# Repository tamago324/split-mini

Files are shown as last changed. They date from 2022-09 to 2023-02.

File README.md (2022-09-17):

# split mini

小さな分割キーボードです。

## ライセンス

<br />この 作品 は <a rel="license" href="http://creativecommons.org/licenses/by/4.0/">クリエイティブ・コモンズ 表示 4.0 国際 ライセンス</a>の下に提供されています。

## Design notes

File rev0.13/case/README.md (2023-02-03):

## ボトムケースとトップケースをねじ止めする

* [ネジ](https://wilco.jp/products/F/FPP-N.html#page1)
  * M2 の 5mm

## ケースのデータ (Onshape)

https://cad.onshape.com/documents/96d7513a54998d2b6436f8c3/w/2520ae499280115528b36742/e/f078bf5b49cbb926b5d52385

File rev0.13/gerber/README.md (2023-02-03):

## Elecrow に発注するとき

* split-mini__left_94.8x81.85mm_for_Elecrow.zip
  * 1.2mm
* split-mini__right_94.8x81.85mm_for_Elecrow.zip
  * 1.2mm
* split-mini__switch_plate_94.8x83.85mm_for_Elecrow.zip
  * 1.6mm

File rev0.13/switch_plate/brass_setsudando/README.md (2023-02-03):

とりあえず FR4 で組み立ててみることにしたため、まだ発注していない

## 切断堂さんに発注するときに使用する DXF ファイル

切断堂さんに発注するときには、スイッチの穴は 13.85 にする必要があるため、そのようにしている

1つのDXFファイルでオモテウラで2つを発注すれば良いのかもって思っているけど、それでできるのかはメールで問い合わせて見る必要がありそう

### 発注

* 厚さ：1.5mm
* 表面仕上げ：サンドブラスト

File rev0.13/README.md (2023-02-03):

## split mini rev0.13

* [KLE](http://www.keyboard-layout-editor.com/#/gists/a34cca681a2130594f6d9f4207fc3f27)
* https://kbplate.ai03.com/ でプレートデータを作成
  * width: 17
  * height: 17
* 左右分割キーボード
* 狭ピッチ
  * キーキャップは専用のものを使う (底面が16mmのやつを使うことにする)
  * [雰囲気で作ったキーキャップ](https://github.com/tamago324/small-keycaps)
* MXのみ 対応
* 100mmx100mm以下のため、Elecrow で1ドルで発注可能
* [QMK firmware](https://github.com/tamago324/qmk_firmware/tree/tamago324/keyboards/tamago324/splitmini)
  * rev13 のディレクトリのため、`nix-shell --run 'sudo make tamago324/splitmini/rev13:tamago324:flash'` のようにして書き込み可能

## 部品一覧

片手分

| 名前 | 値 | 備考 | 個数 | 部品番号 | リンク |
| --- | --- | --- | ---  | --- | --- |
| コンデンサ | 0.1uF | 0805 (2012) | 3 | C2、C3、C4 | [Digikey][1]  |
| コンデンサ | 10uF  | 0805 (2012) | 1 | C5 | [Digikey][2]  |
| コンデンサ | 1uF | 0805 (2012) | 1 | C1 | [Digikey][3]  |
| コンデンサ | 22pF  | 0805 (2012) | 2 | C6、C7 | [Digikey][4]  |
| ヒューズ | 500mA | 1206 (3216) | 1 | F1 | [Digikey][5]  |
| 抵抗 | 5.1kΩ  | 0805 (2012) | 2 | R1、R2 | [モノタロウ][13]  |
| 抵抗 | 22 | 0805 (2012) | 2 | R3、R4 | [Digikey][7]  |
| 抵抗 | 10kΩ  | 0805 (2012) | 2 | R5、R6 | [Digikey][6]  |
| 水晶発振子 | 16MHz | 3225 4pin 3.2x2.5mm | 1 | Y1 | [Digikey][8]  |
| TRRSジャック (MJ-4PP-9) | - | - | 1 | J2 | [遊舎工房][9] |
| ATmega32U4 | - | 10x10mm P0.8mm | 1 | U1 | [Digikey][10] |
| USBコネクタ (Type-C) | - | 5077CR-16SMC2-BK-TR | 1 | J1 | [秋月電子][11] |
| リセットスイッチ | - | SKRPACE010 | 1 | RESET1 | [秋月電子][12] |

### 実際に購入したところ

| 名前 | 値 | 備考 | 個数 | 部品番号 | リンク |
| --- | --- | --- | ---  | --- | --- |
| コンデンサ | 0.1uF | 0805 (2012) | 3 | C2、C3、C4 | [秋月電子][21]  |
| コンデンサ | 10uF  | 0805 (2012) | 1 | C5 | [秋月電子][22]  |
| コンデンサ | 1uF | 0805 (2012) | 1 | C1 | [秋月電子][23]  |
| コンデンサ | 22pF  | 0805 (2012) | 2 | C6、C7 | [mouser][24]  |
| ヒューズ | 500mA | 1206 (3216) | 1 | F1 | [mouser][25]  |
| 抵抗 | 5.1kΩ  | 0805 (2012) | 2 | R1、R2 | [モノタロウ][13]  |
| 抵抗 | 22 | 0805 (2012) | 2 | R3、R4 | [mouser][27]  |
| 抵抗 | 10kΩ  | 0805 (2012) | 2 | R5、R6 | [秋月電子][26]  |
| 水晶発振子 | 16MHz | 3225 4pin 3.2x2.5mm | 1 | Y1 | [秋月電子][28]  |
| TRRSジャック (MJ-4PP-9) | - | - | 1 | J1 | [遊舎工房][29] |
| ATmega32U4 | - | 10x10mm P0.8mm | 1 | U1 | [秋月電子][30] |
| USBコネクタ (Type-C) | - | 5077CR-16SMC2-BK-TR | 1 | J1 | [秋月電子][11] |
| リセットスイッチ | - | SKRPACE010 | 1 | SW1 | [秋月電子][12] |

### 画像

#### PCB

#### ケース

## 参考情報

* https://github.com/ruiqimao/keyboard-pcb-guide
* [ATmega32u2直付けのキーパッドを作ろう！](https://taro-hayashi.github.io/LetsMakeaKeypadWithAtmega32u2/)
* [ATMega32u4を使う場合の設計メモ\.md](https://gist.github.com/s-show/286ffb1f5d9c886b514ff7a37e6d8d37)
* [ATmega32U4について学んだこと](https://zenn.dev/koron/articles/a2e220d73800ba)
* [Using USB Type\-C on hobyist projects – The blog of Tyler Ward \(aka scorpia\)](https://www.scorpia.co.uk/2016/03/17/using-usb-type-c-on-hobyist-projects/)

[1]:https://www.digikey.com/product-detail/en/samsung-electro-mechanics/CL21B104MBCNNNC/1276-2450-1-ND/3890536
[2]:https://www.digikey.com/product-detail/en/samsung-electro-mechanics/CL21A106KOQNNNG/1276-6455-1-ND/5958083
[3]:https://www.digikey.com/product-detail/en/samsung-electro-mechanics/CL21B105KAFNNNE/1276-1066-1-ND/3889152
[4]:https://www.digikey.com/product-detail/en/samsung-electro-mechanics/CL21C220JB61PNC/1276-2605-1-ND/3890691
[5]:https://www.digikey.com/product-detail/en/bel-fuse-inc/0ZCJ0050AF2E/507-1803-1-ND/4156312
[6]:https://www.digikey.com/product-detail/en/panasonic-electronic-components/ERA-6AEB103V/P10KDACT-ND/1465971
[7]:https://www.digikey.com/product-detail/en/panasonic-electronic-components/ERJ-6GEYJ220V/P22ACT-ND/87316
[8]:https://www.digikey.com/product-detail/en/CX3225SB16000D0GZJC1/1253-1698-1-ND/5995245/?itemSeq=264931473
[9]:https://shop.yushakobo.jp/products/a0800tr-01-1
[10]:https://www.digikey.com/product-detail/en/microchip-technology/ATMEGA32U4-AU/ATMEGA32U4-AU-ND/1914602
[11]:https://akizukidenshi.com/catalog/g/gC-14356/
[12]:https://akizukidenshi.com/catalog/g/gP-06185/
[13]:https://www.monotaro.com/g/04269677/?t.q=5.1K%20%E3%83%81%E3%83%83%E3%83%97%E6%8A%B5%E6%8A%97

[21]:https://akizukidenshi.com/catalog/g/gP-00093/
[22]:https://akizukidenshi.com/catalog/g/gP-13606/
[23]:https://akizukidenshi.com/catalog/g/gP-15331/
[24]:https://www.mouser.jp/ProductDetail/Samsung-Electro-Mechanics/CL21C220JB61PNC?qs=uvHW8qpSFORHMf5PV5yOeg%3D%3D
[25]:https://www.mouser.jp/ProductDetail/Bel-Fuse/0ZCJ0050AF2E?qs=SRYZG9HaIQ3Oqm1PQp276Q%3D%3D
[26]:https://akizukidenshi.com/catalog/g/gR-11797/
[27]:https://www.mouser.jp/ProductDetail/Panasonic/ERJ-6GEYJ220V?qs=tQNqqtTOejK5J3XsPrLscg%3D%3D
[28]:https://akizukidenshi.com/catalog/g/gP-02457/
[29]:https://shop.yushakobo.jp/products/a0800tr-01-1
[30]:https://akizukidenshi.com/catalog/g/gI-09835/

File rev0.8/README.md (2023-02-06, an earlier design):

## split mini rev0.8

* XIAO RP2040 を使用
* [KLE](http://www.keyboard-layout-editor.com/#/gists/249dbe1a0262937117484ad3b4d1d6fd)
* https://kbplate.ai03.com/ でプレートデータを作成
  * width: 16.5
  * height: 16.5
* 左右分割キーボード
* 狭ピッチ
  * キーキャップは専用のものを使う (底面が16mmのやつを使うことにする)
* MX 対応
* 100mmx100mm以下のため、Elecrow で1ドルで発注可能
  * PCB、トッププレート1つ、ボトムプレートの3つを3ドルで発注できて、2セット組み立てられる
* [QMK firmware](https://github.com/tamago324/qmk_firmware/tree/tamago324/keyboards/tamago324/splitmini)

### ケースを使いたいとき

* メインPCB は1mmにする
* スペーサーは9mm にすると、1.5mmのPORONをひける！

## Pictures

### PCB

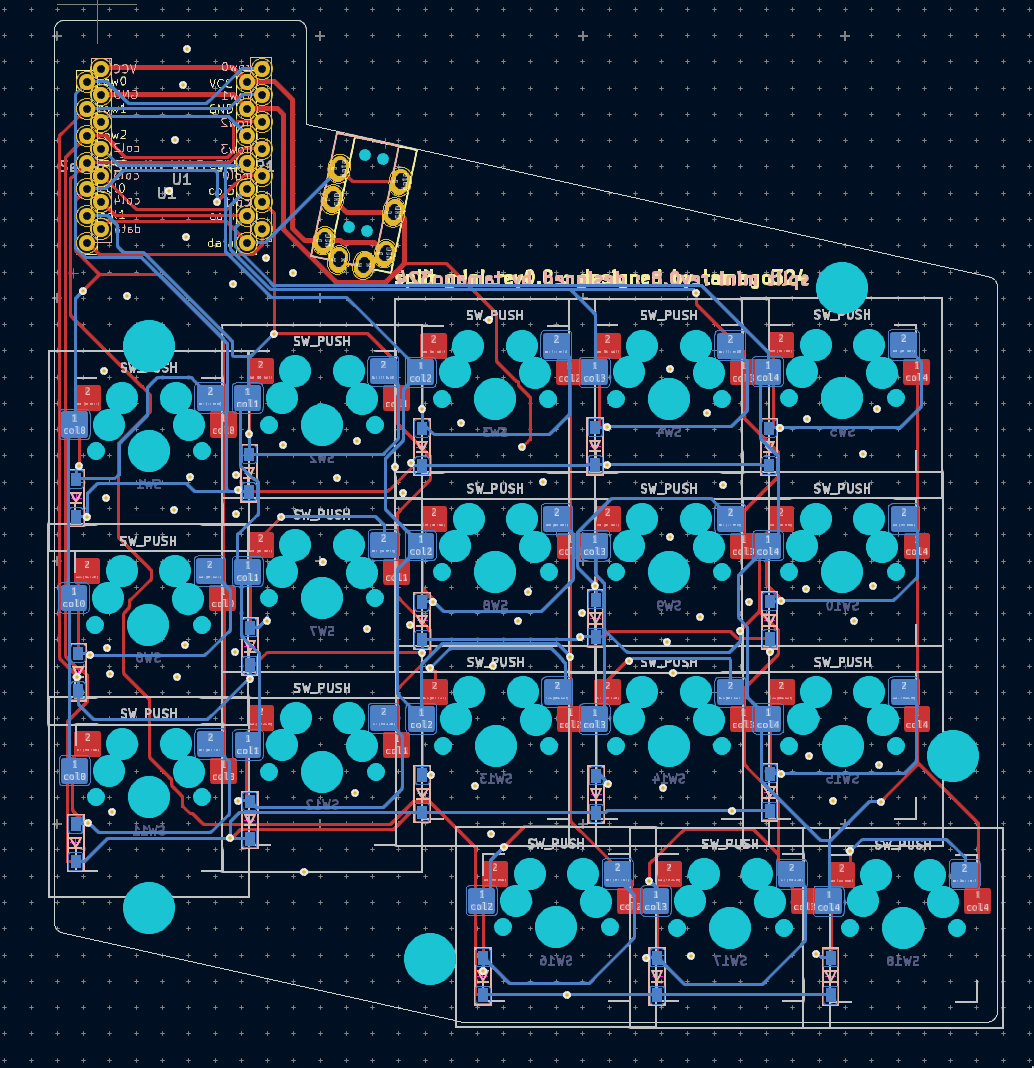
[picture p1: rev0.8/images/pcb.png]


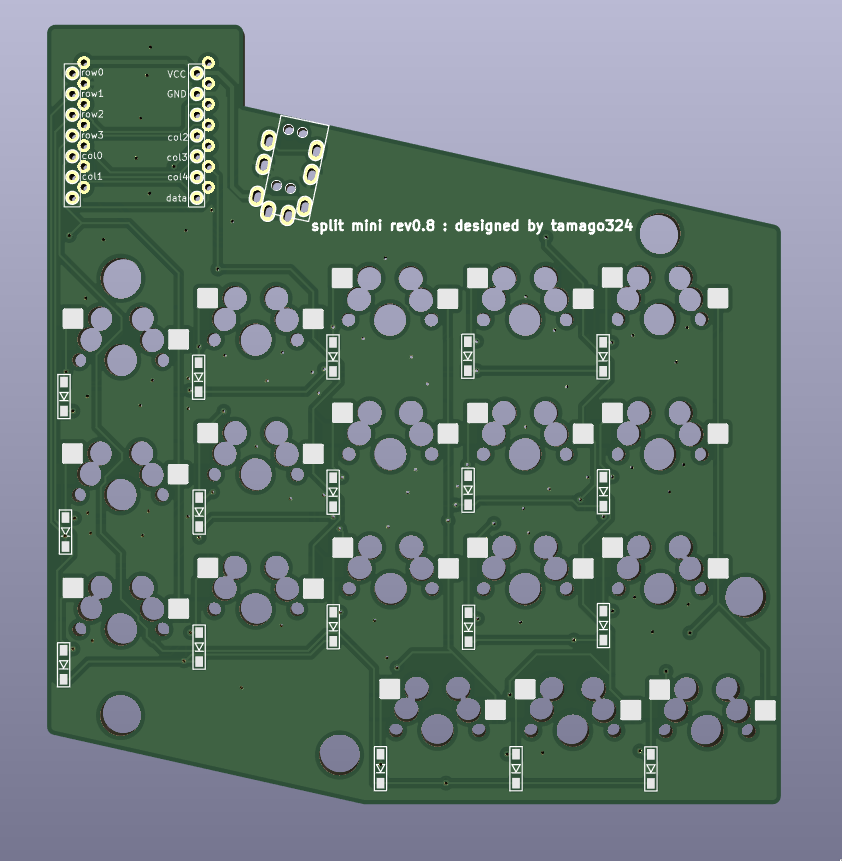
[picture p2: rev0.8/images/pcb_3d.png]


### Top plate

### bottom plate

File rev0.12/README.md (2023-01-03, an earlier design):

## split mini rev0.12

* ProMicro を使用
* [KLE](http://www.keyboard-layout-editor.com/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,%20tatewo%2017.5%20ni%20sitai%3B&@_y:0.75&x:3&a:7%3B&=&=%3B&@_y:-0.9&x:5%3B&=%3B&@_y:-0.9500000000000001&x:2%3B&=%3B&@_y:-0.7&x:1%3B&=%3B&@_y:-0.44999999999999996&x:3%3B&=&=%3B&@_y:-0.8999999999999999&x:5%3B&=%3B&@_y:-0.9500000000000002&x:2%3B&=%3B&@_y:-0.6999999999999997&x:1%3B&=%3B&@_y:-0.4500000000000002&x:3%3B&=&=%3B&@_y:-0.8999999999999999&x:5%3B&=%3B&@_y:-0.9500000000000002&x:2%3B&=%3B&@_y:-0.6999999999999997&x:1%3B&=%3B&@_y:-0.3500000000000001&x:3.3%3B&=&_w:1.25%3B&=%3B&@_r:10&y:-2.05&x:6.3&w:1.25%3B&=)
* https://kbplate.ai03.com/ でプレートデータを作成
  * width: 16.5
  * height: 17.5
* 左右分割キーボード
* 狭ピッチ
  * キーキャップは専用のものを使う (底面が16mmのやつを使うことにする)
* MX 対応
* 100mmx100mm以下のため、Elecrow で1ドルで発注可能
  * PCB、トッププレート1つ、ボトムプレートの3つを3ドルで発注できて、2セット組み立てられる
* Trackball module をつけられる
  * 線をはんだ付けすることで使用可能になる想定
  * Aliexpress で売っているもの
    * [ケーブル](https://ja.aliexpress.com/item/4000898605030.html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)
    * [コネクタ](https://ja.aliexpress.com/item/4001115739803.html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)

## Pictures

### PCB

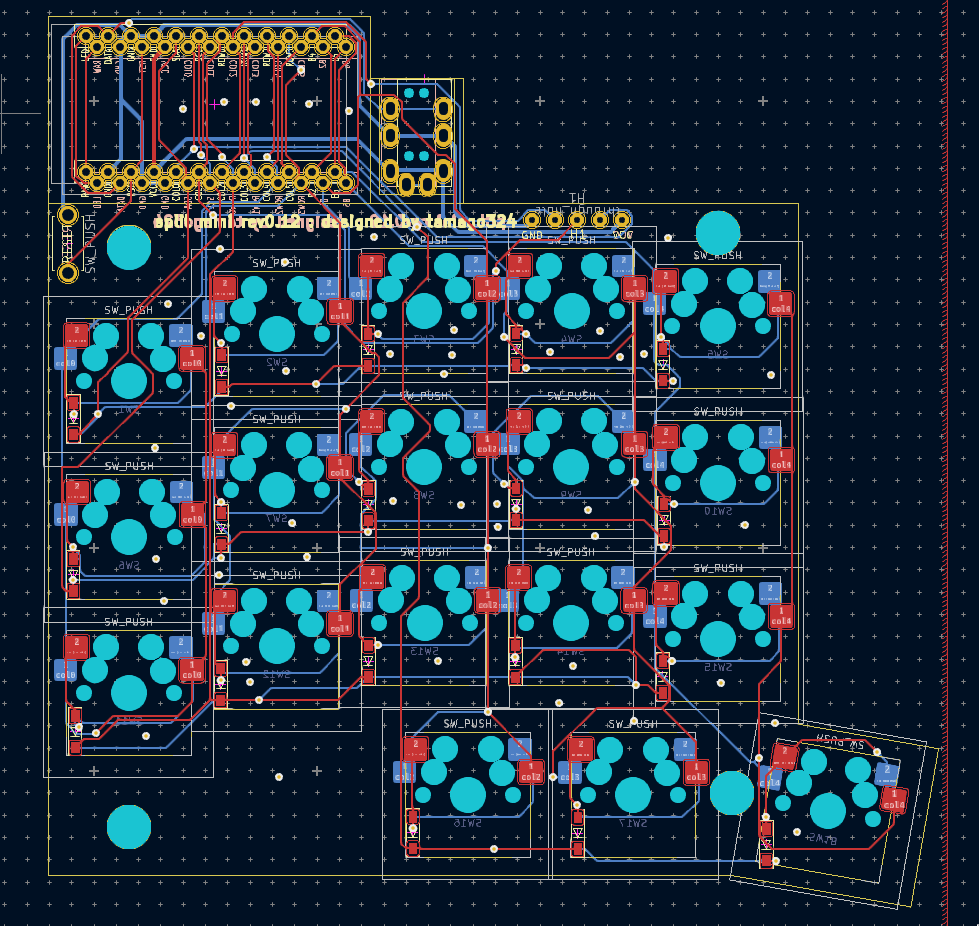
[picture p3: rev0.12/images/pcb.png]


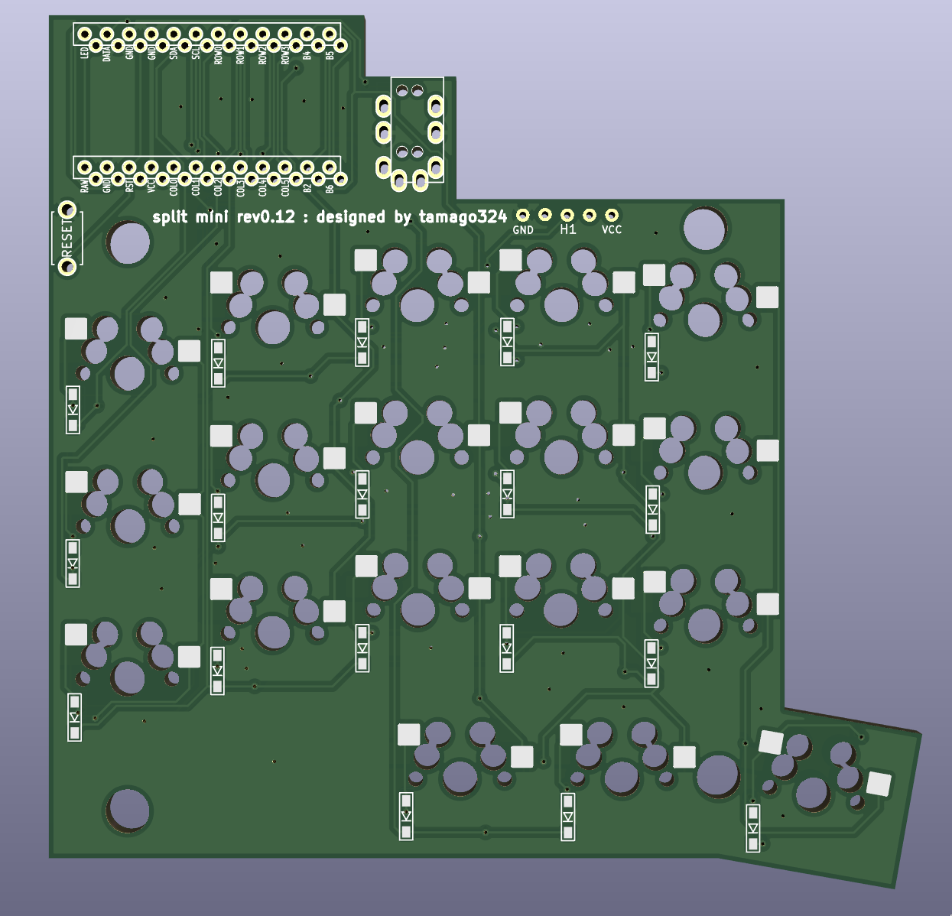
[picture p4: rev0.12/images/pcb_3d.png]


### Top plate

### bottom plate

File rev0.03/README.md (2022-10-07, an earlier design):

## split mini rev0.3

* XIAO RP2040 を使用
* [KLE](http://www.keyboard-layout-editor.com/#/gists/d7ed01c506e9d3b2c2adfb04fcaa3432)
* https://kbplate.ai03.com/ でプレートデータを作成
  * width: 16.5
  * height: 17.5
* 左右分割キーボード
* 狭ピッチ
  * キーキャップは専用のものを使う (底面が16mmのやつを使うことにする)
* MX/Choc 対応
* 100mmx100mm以下のため、Elecrow で1ドルで発注可能
  * PCB、トッププレート2つ、ボトムプレートの4つを4ドルで発注できて、2セット組み立てられる
* [QMK firmware](https://github.com/tamago324/qmk_firmware/tree/tamago324/keyboards/tamago324/splitmini)

## Pictures

### PCB

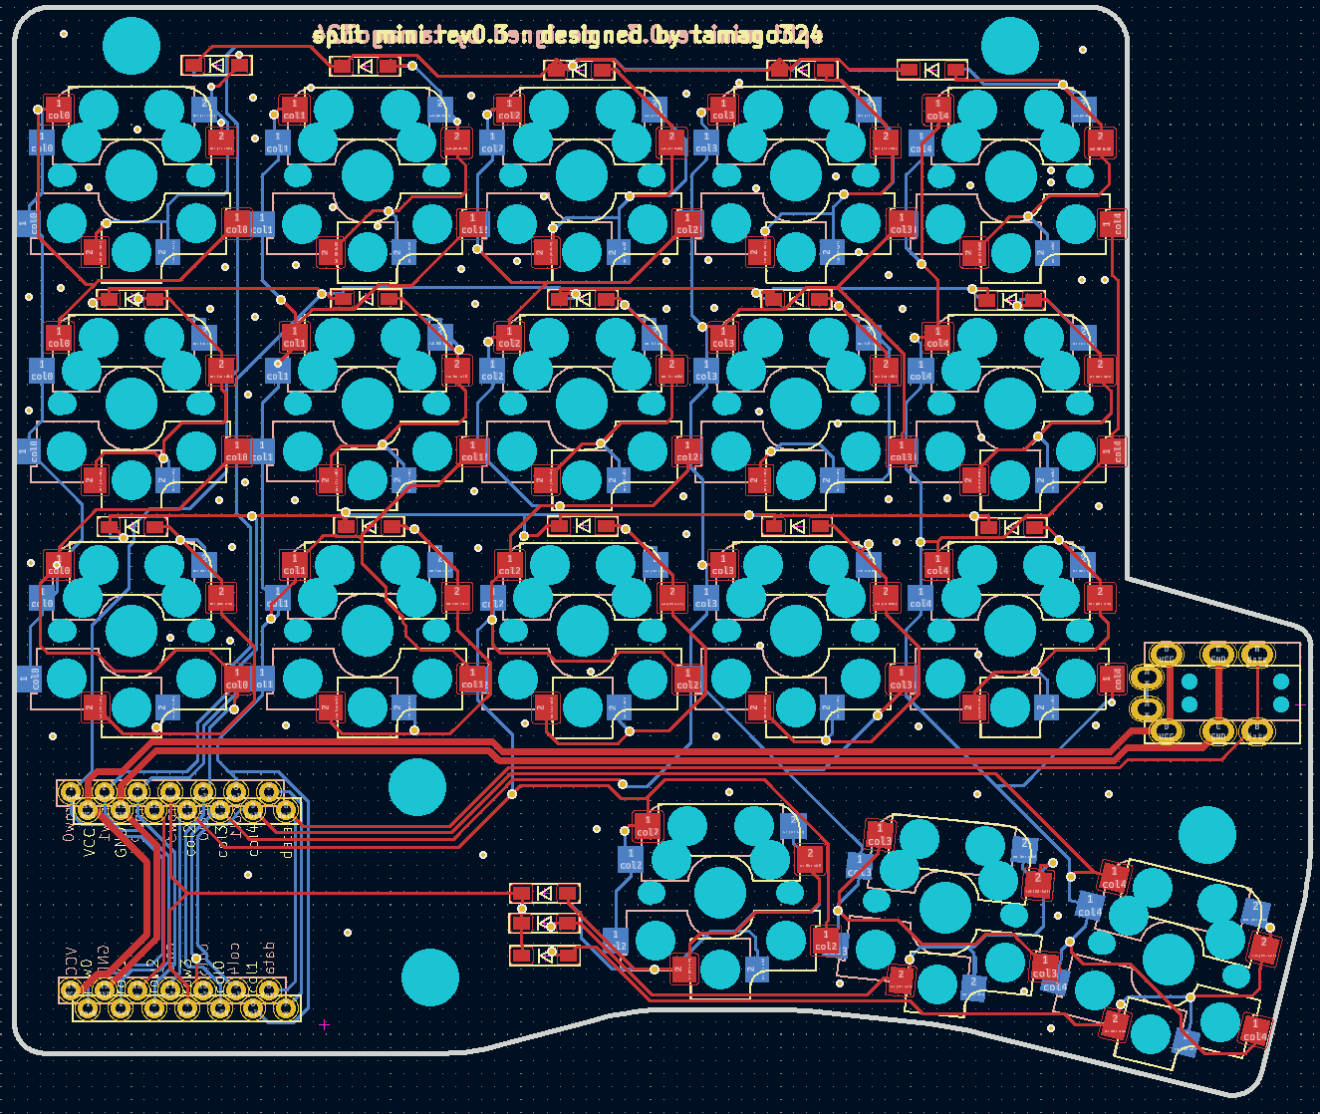
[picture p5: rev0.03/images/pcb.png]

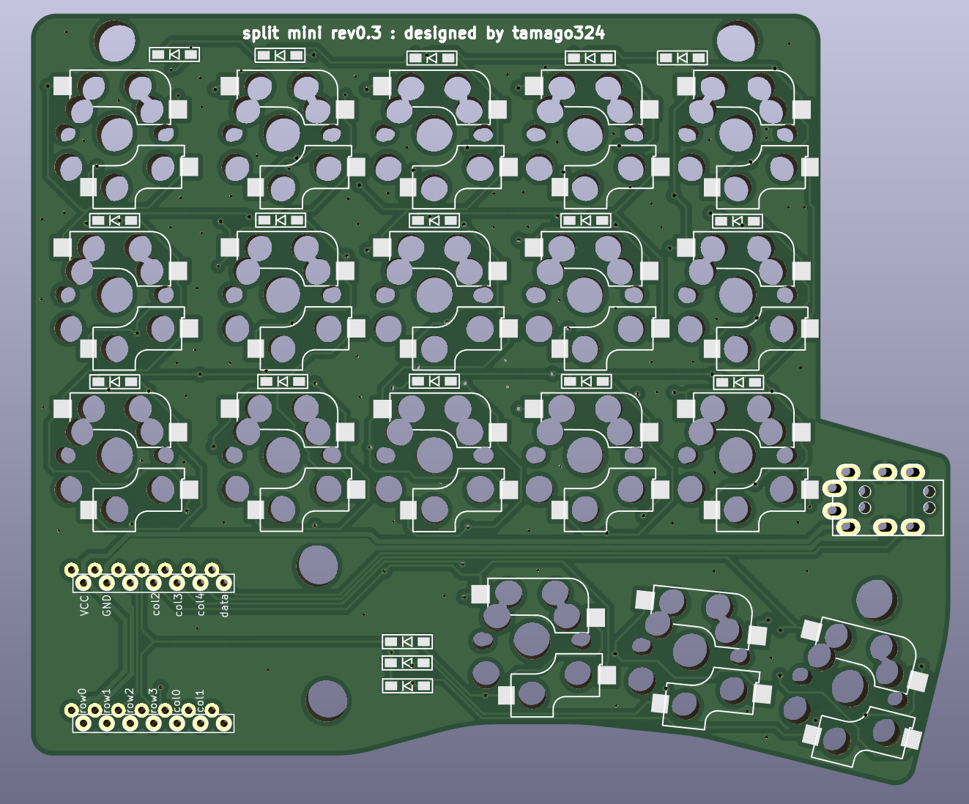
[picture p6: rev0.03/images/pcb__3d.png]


### Top plate

#### 親指以外

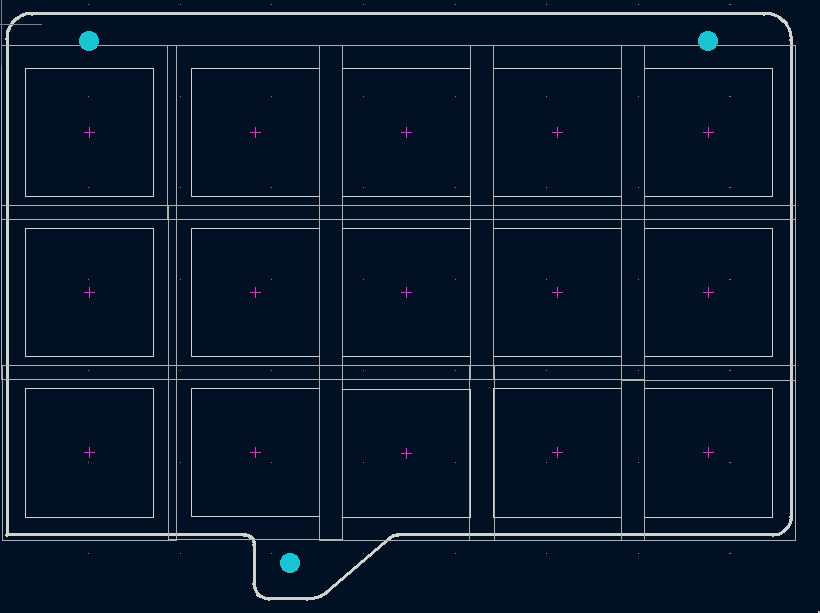
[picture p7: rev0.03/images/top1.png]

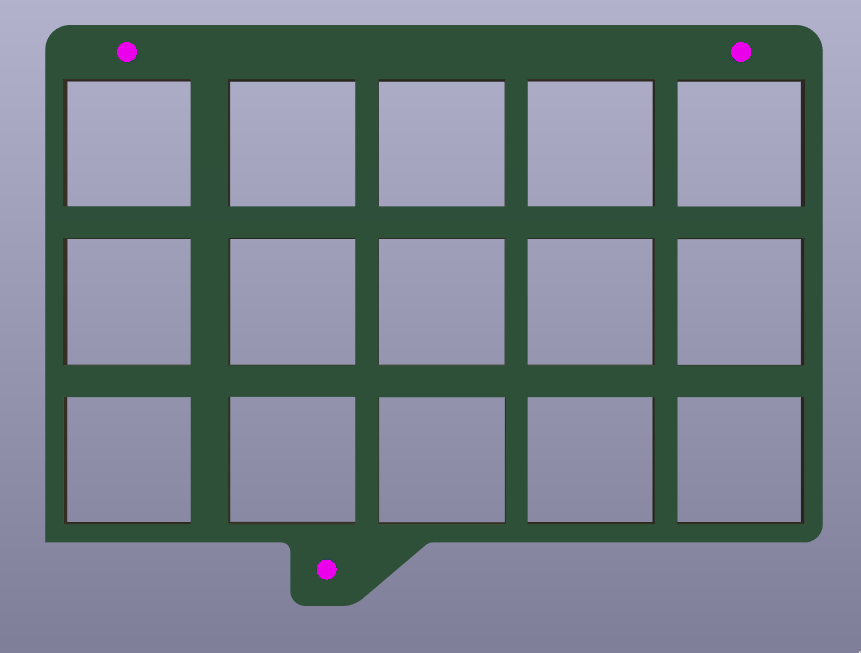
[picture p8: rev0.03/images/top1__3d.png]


#### 親指部分

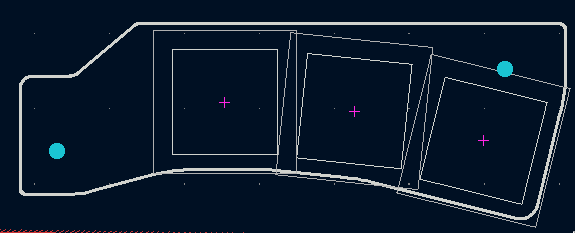
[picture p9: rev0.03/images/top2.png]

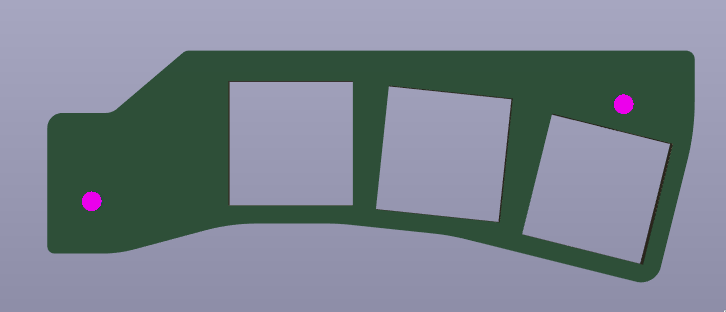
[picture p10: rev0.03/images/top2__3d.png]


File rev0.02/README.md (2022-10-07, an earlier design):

## split mini rev0.2

* XIAO RP2040 を使用
* [KLE](http://www.keyboard-layout-editor.com/#/gists/d7ed01c506e9d3b2c2adfb04fcaa3432)
* https://kbplate.ai03.com/ でプレートデータを作成
  * width: 16.5
  * height: 17.5

* 左右分割キーボード
* 狭ピッチ
  * キーキャップは専用のものを使う (底面が16mmのやつを使うことにする)
* 親指は Choc もつけられる

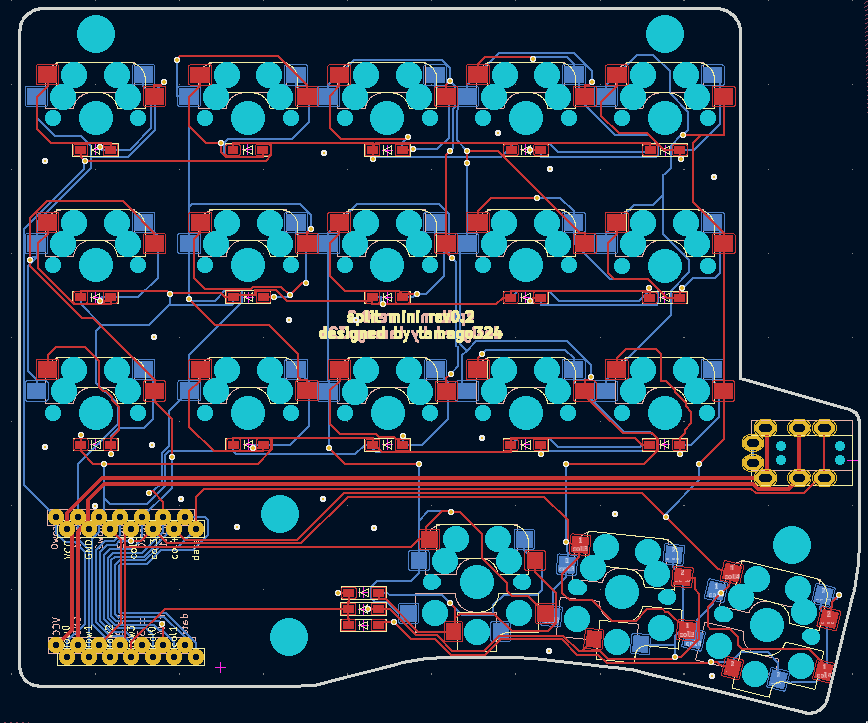
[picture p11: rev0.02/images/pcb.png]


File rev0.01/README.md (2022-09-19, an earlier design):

# split mini rev0.1

* XIAO RP2040 を使用
* [KLE](http://www.keyboard-layout-editor.com/#/gists/fbe317ca72d8030fb684be89b4dfa688)
* https://kbplate.ai03.com/ でプレートデータを作成
  * width: 16.5
  * height: 16.5

* 左右分割キーボード
* 狭ピッチ

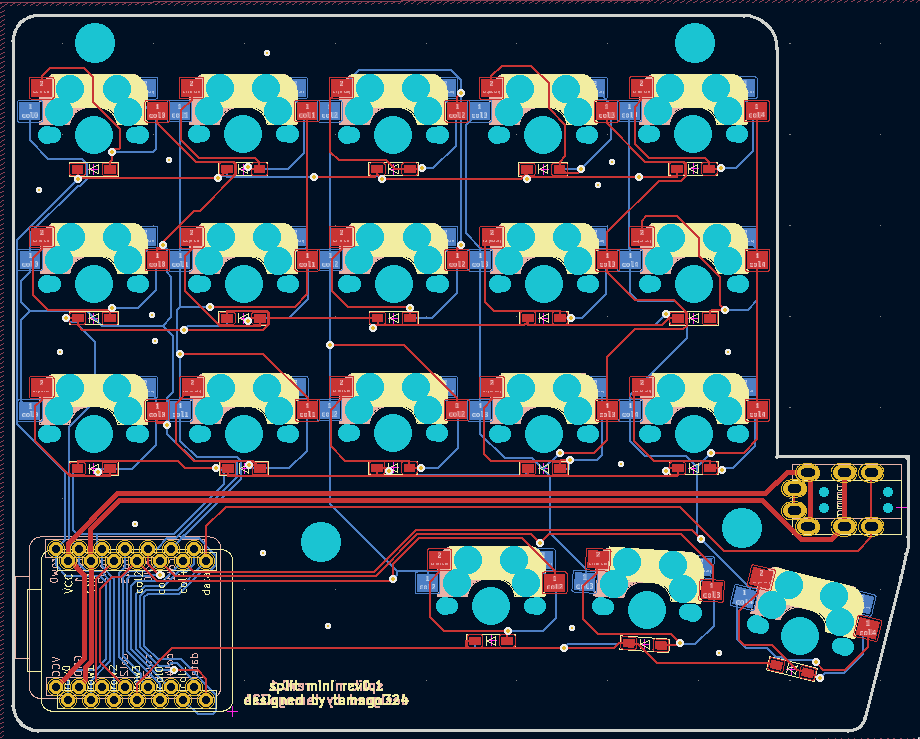
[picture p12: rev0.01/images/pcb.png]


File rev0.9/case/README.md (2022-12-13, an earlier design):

## ボトムケースとトップケースをねじ止めする

* [ネジ](https://wilco.jp/products/F/FPP-N.html#page1)
  * M2 の 5mm

M3 でもいいのかなて思っているけど、その分ケースを大きくしないといけなくなるから、M2 でもいいのかも

## 磁石を使って、パームレストとキーボードをくっつける場合

* [磁石](https://www.amazon.co.jp/dp/B09SWFP9PC)
* [ネジ](https://wilco.jp/products/F/FPF-N.html#page3)
  * M3 の 8mm

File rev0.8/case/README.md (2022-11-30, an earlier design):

## ケース

[Onshape](https://cad.onshape.com/documents/99ac2a040ba6359cc14b7947/w/5db2decaeaf8618e452eca8a/e/1233a5ba88eb4c997b89bcf1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)

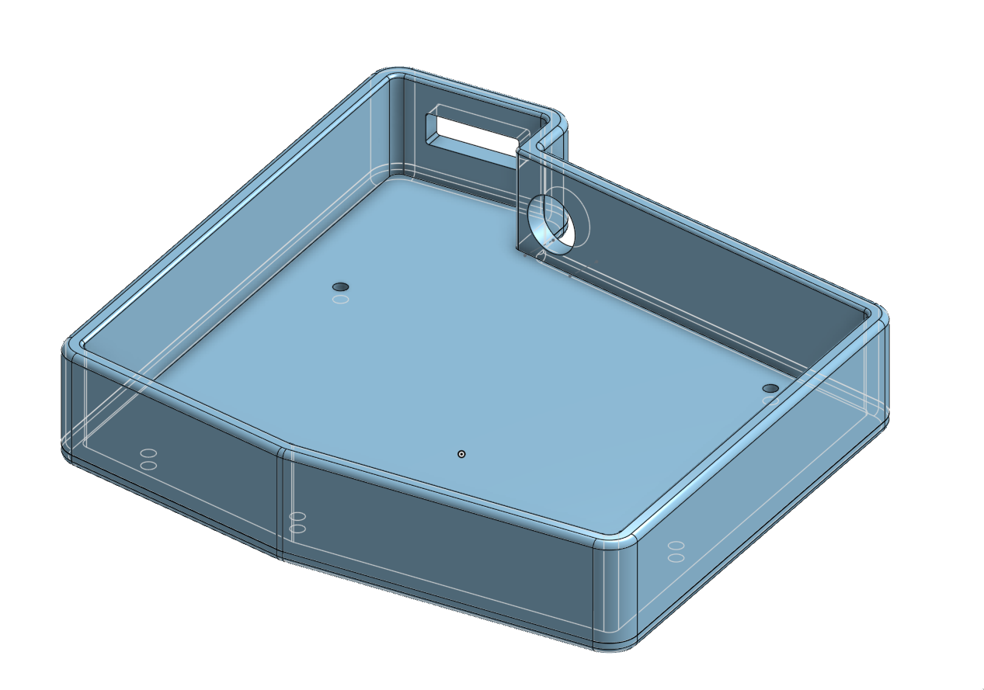
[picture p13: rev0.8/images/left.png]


* left.stl
* right.stl

## パームレスト付きケース

[Onshape](https://cad.onshape.com/documents/f12508bcbbf23d3b0f91d463/w/c02f327155a34e37a0b70303/e/b87303f77526a098237cbe79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)

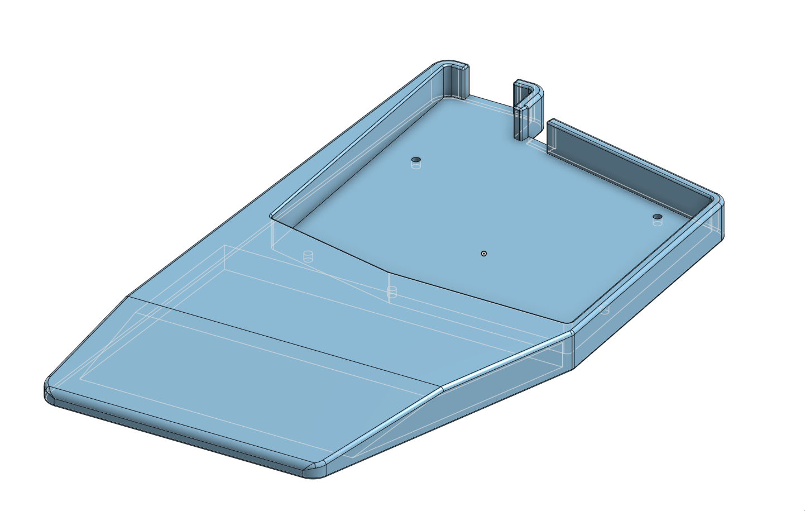
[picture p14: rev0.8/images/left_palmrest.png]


* left_with_palmrest.stl
* right_with_palmrest.stl

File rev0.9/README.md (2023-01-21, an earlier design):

## split mini rev0.9

* [KLE](http://www.keyboard-layout-editor.com/#/gists/249dbe1a0262937117484ad3b4d1d6fd)
* https://kbplate.ai03.com/ でプレートデータを作成
  * width: 16.5
  * height: 16.5
* 左右分割キーボード
* 狭ピッチ
  * キーキャップは専用のものを使う (底面が16mmのやつを使うことにする)
  * [雰囲気で作ったキーキャップ](https://github.com/tamago324/small-keycaps)
* MXのみ 対応
* 100mmx100mm以下のため、Elecrow で1ドルで発注可能
* [QMK firmware](https://github.com/tamago324/qmk_firmware/tree/tamago324/keyboards/tamago324/splitmini)
  * rev09 のディレクトリのため、`nix-shell --run 'sudo make tamago324/splitmini/rev09:tamago324:flash'` のようにして書き込み可能

## 部品一覧

片手分

| 名前 | 値 | 備考 | 個数 | 部品番号 | リンク |
| --- | --- | --- | ---  | --- | --- |
| コンデンサ | 0.1uF | 0805 (2012) | 3 | C2、C3、C4 | [Digikey][1]  |
| コンデンサ | 10uF  | 0805 (2012) | 1 | C5 | [Digikey][2]  |
| コンデンサ | 1uF | 0805 (2012) | 1 | C1 | [Digikey][3]  |
| コンデンサ | 22pF  | 0805 (2012) | 2 | C6、C7 | [Digikey][4]  |
| ヒューズ | 500mA | 1206 (3216) | 1 | F1 | [Digikey][5]  |
| 抵抗 | 5.1kΩ  | 0805 (2012) | 2 | R1、R2 | [モノタロウ][13]  |
| 抵抗 | 22 | 0805 (2012) | 2 | R3、R4 | [Digikey][7]  |
| 抵抗 | 10kΩ  | 0805 (2012) | 2 | R5、R6 | [Digikey][6]  |
| 水晶発振子 | 16MHz | 3225 4pin 3.2x2.5mm | 1 | Y1 | [Digikey][8]  |
| TRRSジャック (MJ-4PP-9) | - | - | 1 | J2 | [遊舎工房][9] |
| ATmega32U4 | - | 10x10mm P0.8mm | 1 | U1 | [Digikey][10] |
| USBコネクタ (Type-C) | - | 5077CR-16SMC2-BK-TR | 1 | J1 | [秋月電子][11] |
| リセットスイッチ | - | SKRPACE010 | 1 | RESET1 | [秋月電子][12] |

### 実際に購入したところ

| 名前 | 値 | 備考 | 個数 | 部品番号 | リンク |
| --- | --- | --- | ---  | --- | --- |
| コンデンサ | 0.1uF | 0805 (2012) | 3 | C2、C3、C4 | [秋月電子][21]  |
| コンデンサ | 10uF  | 0805 (2012) | 1 | C5 | [秋月電子][22]  |
| コンデンサ | 1uF | 0805 (2012) | 1 | C1 | [秋月電子][23]  |
| コンデンサ | 22pF  | 0805 (2012) | 2 | C6、C7 | [mouser][24]  |
| ヒューズ | 500mA | 1206 (3216) | 1 | F1 | [mouser][25]  |
| 抵抗 | 5.1kΩ  | 0805 (2012) | 2 | R1、R2 | [モノタロウ][13]  |
| 抵抗 | 22 | 0805 (2012) | 2 | R3、R4 | [mouser][27]  |
| 抵抗 | 10kΩ  | 0805 (2012) | 2 | R5、R6 | [秋月電子][26]  |
| 水晶発振子 | 16MHz | 3225 4pin 3.2x2.5mm | 1 | Y1 | [秋月電子][28]  |
| TRRSジャック (MJ-4PP-9) | - | - | 1 | J1 | [遊舎工房][29] |
| ATmega32U4 | - | 10x10mm P0.8mm | 1 | U1 | [秋月電子][30] |
| USBコネクタ (Type-C) | - | 5077CR-16SMC2-BK-TR | 1 | J1 | [秋月電子][11] |
| リセットスイッチ | - | SKRPACE010 | 1 | SW1 | [秋月電子][12] |

### 画像

#### PCB

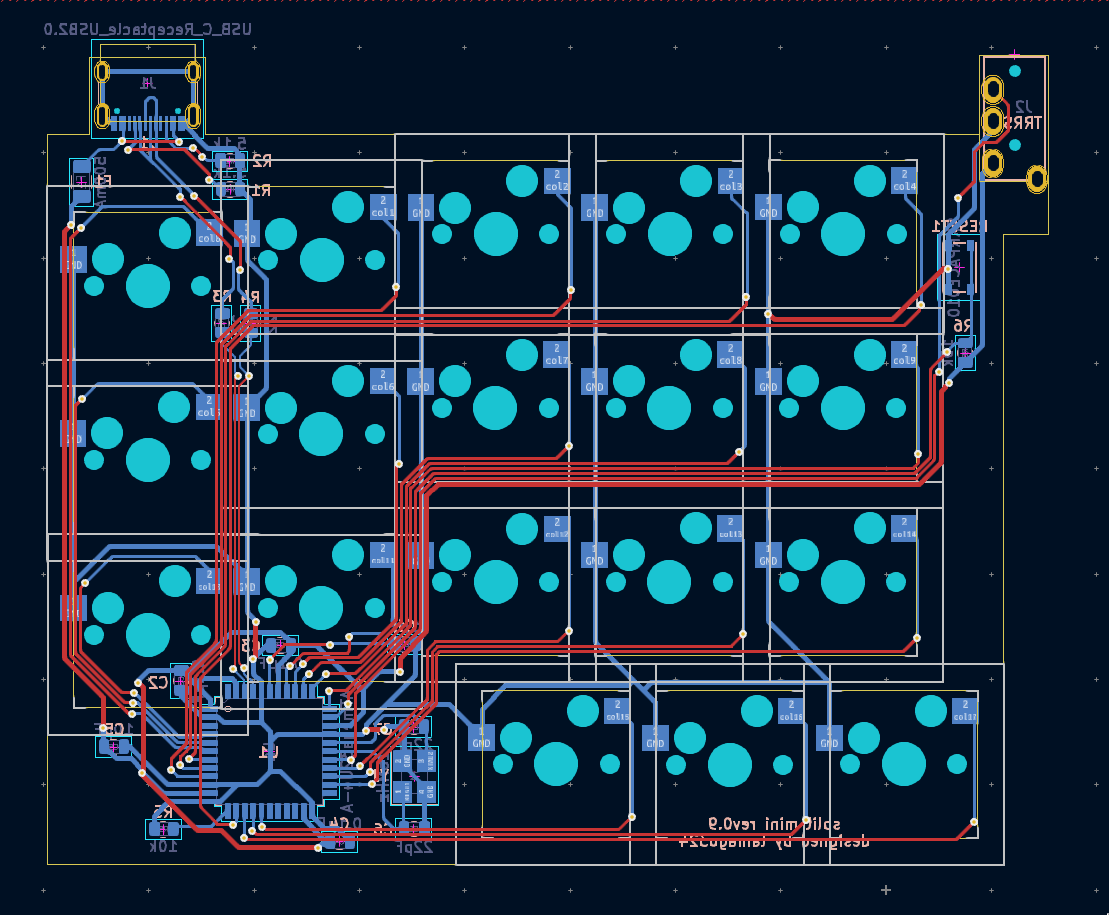
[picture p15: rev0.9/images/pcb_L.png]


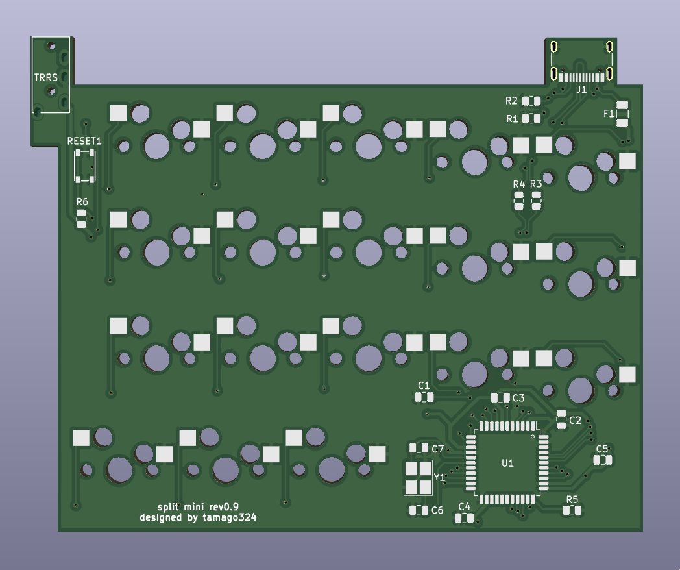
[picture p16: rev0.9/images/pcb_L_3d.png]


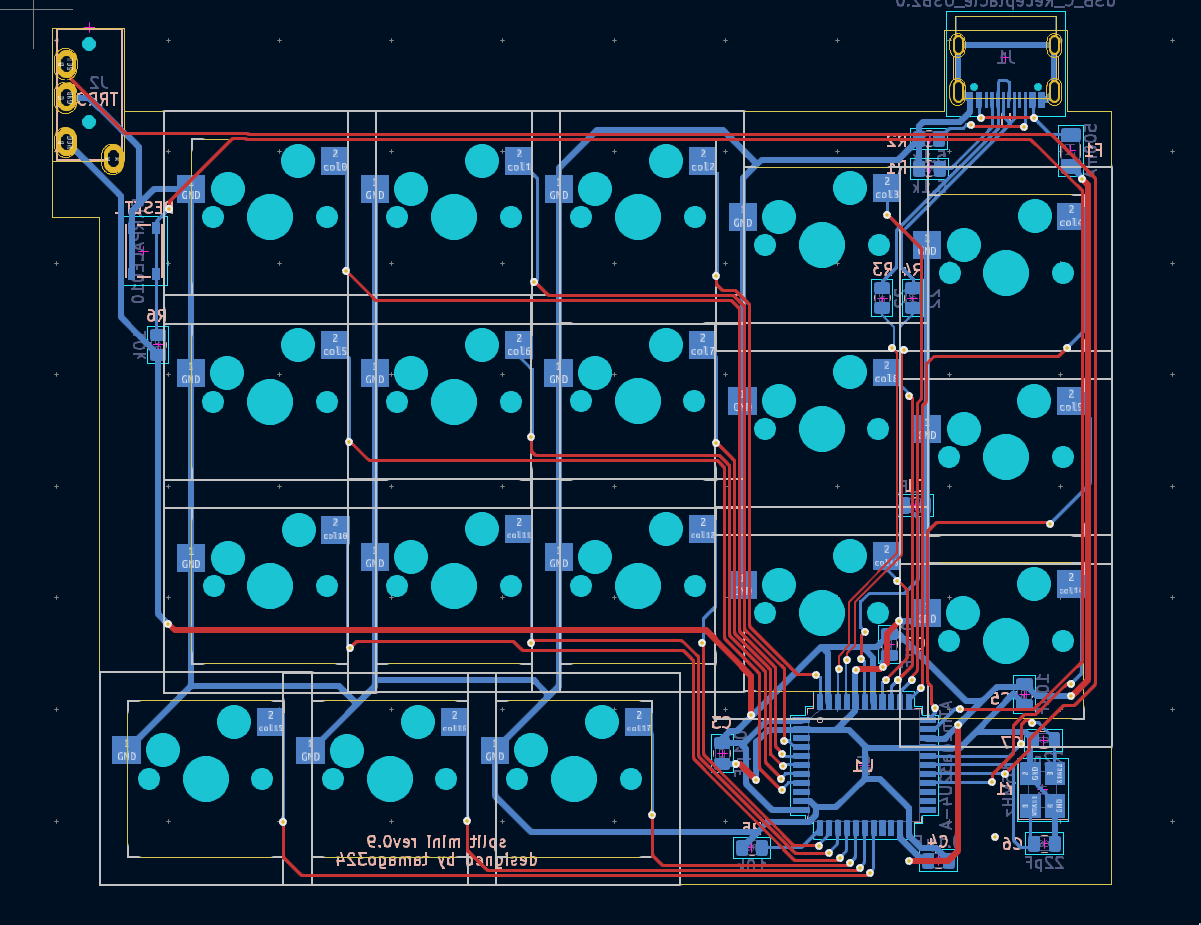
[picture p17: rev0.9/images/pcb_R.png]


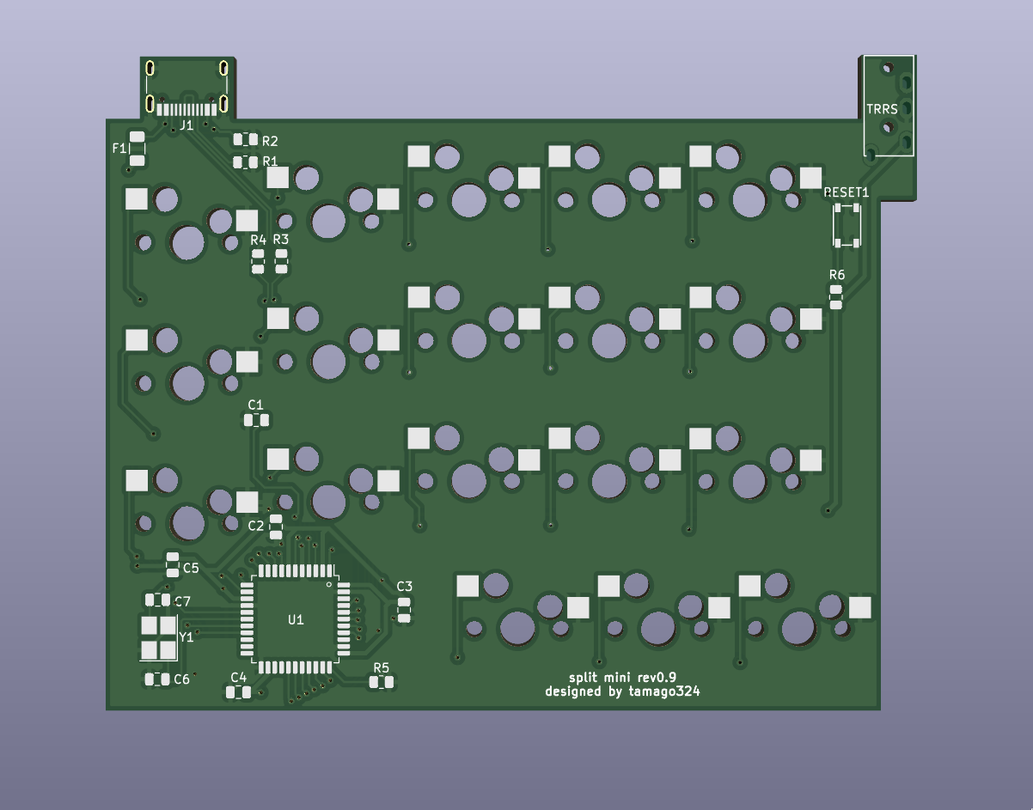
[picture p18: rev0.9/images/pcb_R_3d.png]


#### ケース

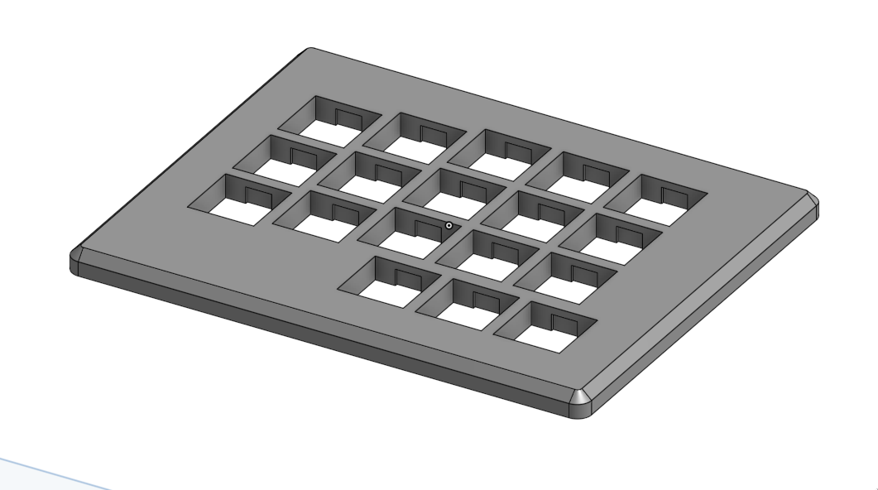
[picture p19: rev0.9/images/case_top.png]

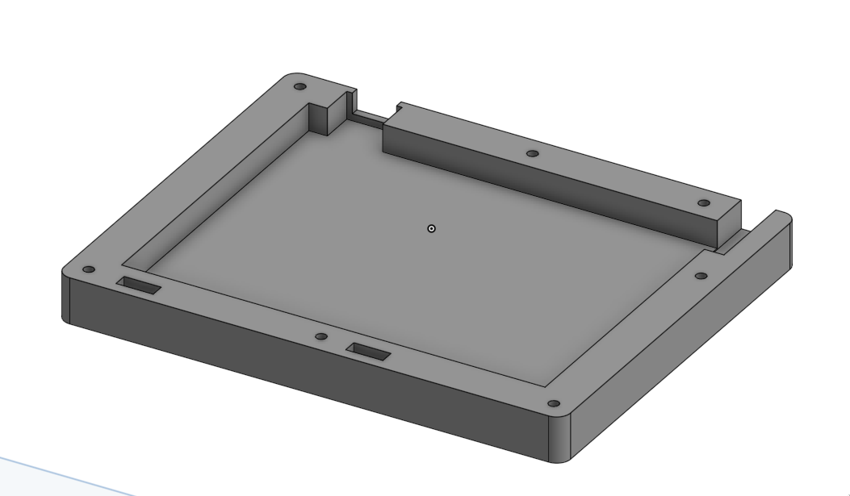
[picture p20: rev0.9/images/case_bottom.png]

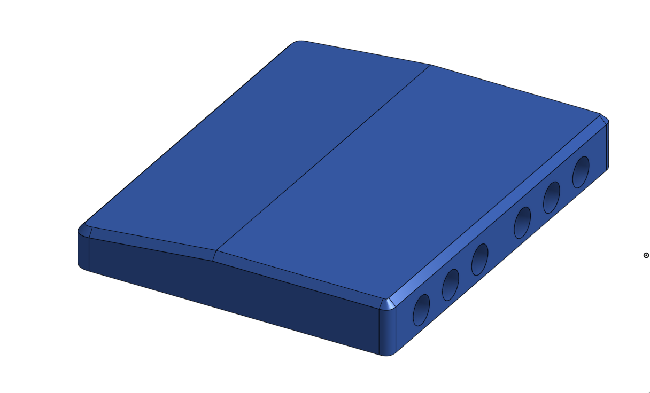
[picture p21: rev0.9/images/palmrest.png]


## 参考情報

* https://github.com/ruiqimao/keyboard-pcb-guide
* [ATmega32u2直付けのキーパッドを作ろう！](https://taro-hayashi.github.io/LetsMakeaKeypadWithAtmega32u2/)
* [ATMega32u4を使う場合の設計メモ\.md](https://gist.github.com/s-show/286ffb1f5d9c886b514ff7a37e6d8d37)
* [ATmega32U4について学んだこと](https://zenn.dev/koron/articles/a2e220d73800ba)
* [Using USB Type\-C on hobyist projects – The blog of Tyler Ward \(aka scorpia\)](https://www.scorpia.co.uk/2016/03/17/using-usb-type-c-on-hobyist-projects/)

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

[21]:https://akizukidenshi.com/catalog/g/gP-00093/
[22]:https://akizukidenshi.com/catalog/g/gP-13606/
[23]:https://akizukidenshi.com/catalog/g/gP-15331/
[24]:https://www.mouser.jp/ProductDetail/Samsung-Electro-Mechanics/CL21C220JB61PNC?qs=uvHW8qpSFORHMf5PV5yOeg%3D%3D
[25]:https://www.mouser.jp/ProductDetail/Bel-Fuse/0ZCJ0050AF2E?qs=SRYZG9HaIQ3Oqm1PQp276Q%3D%3D
[26]:https://akizukidenshi.com/catalog/g/gR-11797/
[27]:https://www.mouser.jp/ProductDetail/Panasonic/ERJ-6GEYJ220V?qs=tQNqqtTOejK5J3XsPrLscg%3D%3D
[28]:https://akizukidenshi.com/catalog/g/gP-02457/
[29]:https://shop.yushakobo.jp/products/a0800tr-01-1
[30]:https://akizukidenshi.com/catalog/g/gI-09835/

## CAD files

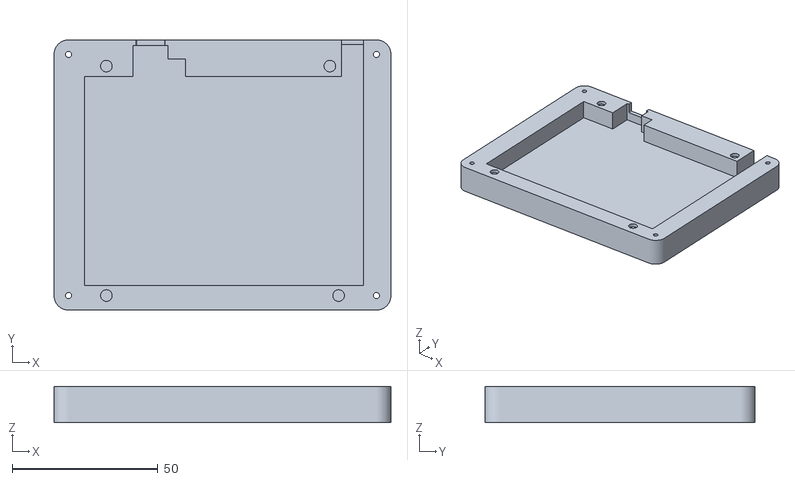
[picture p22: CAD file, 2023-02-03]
rev0.13/case/bottom__L.stl
115.8 x 92.8 x 12.5

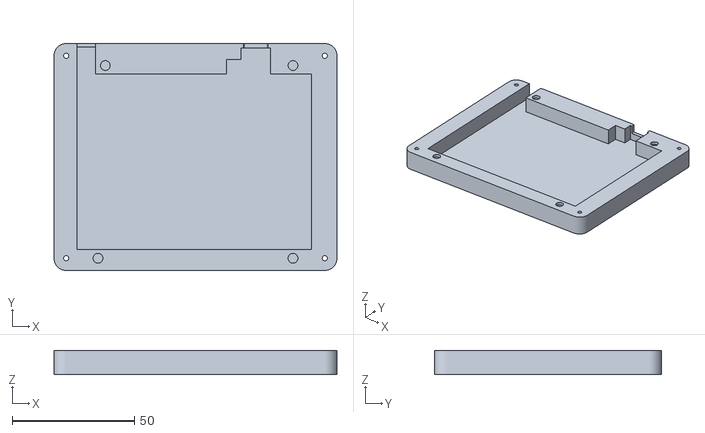
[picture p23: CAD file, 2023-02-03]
rev0.13/case/bottom_thickness_18/bottom__R.stl
115.8 x 92.8 x 10.0

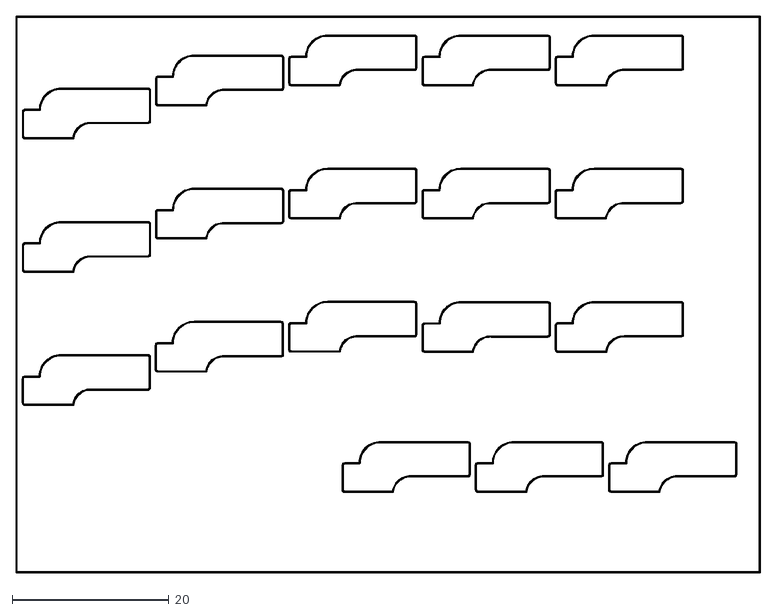
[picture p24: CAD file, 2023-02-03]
rev0.13/form/kicad_base_data/split-mini__form__left.dxf
94.9 x 71.0

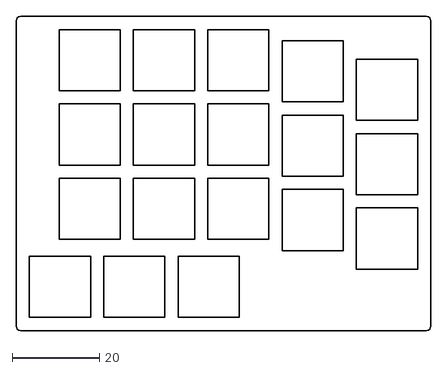
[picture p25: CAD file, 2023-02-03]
rev0.13/form/top__R__form.dxf
94.8 x 71.8

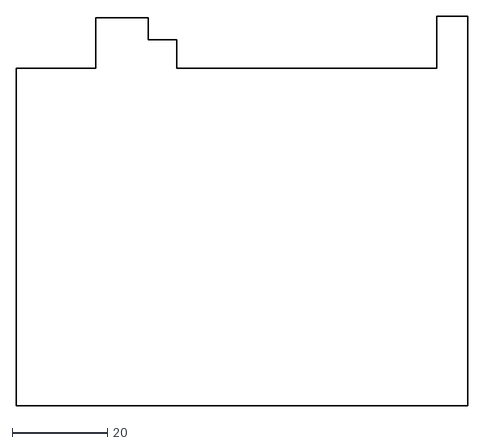
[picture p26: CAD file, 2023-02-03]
rev0.13/pcb edge.dxf
94.8 x 81.8

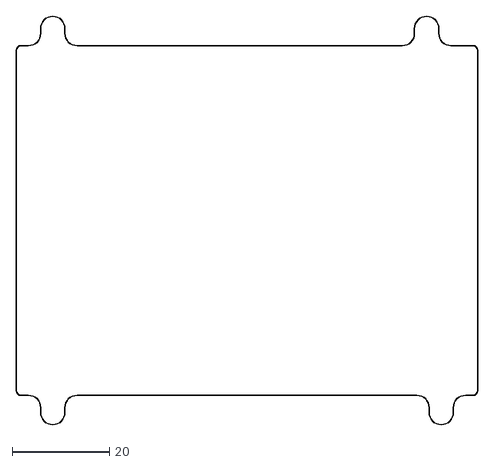
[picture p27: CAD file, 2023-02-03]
rev0.13/switch_plate/fr4/switch_palte_edge.dxf
94.8 x 83.9

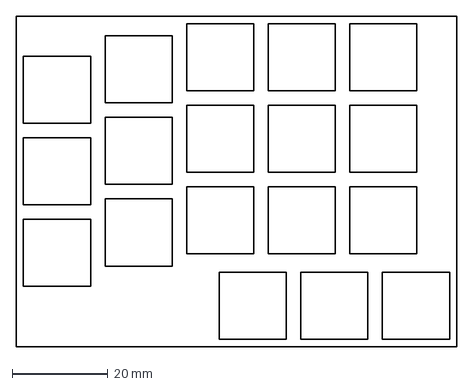
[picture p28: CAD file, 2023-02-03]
rev0.13/base.dxf
91.8 x 68.8 mm

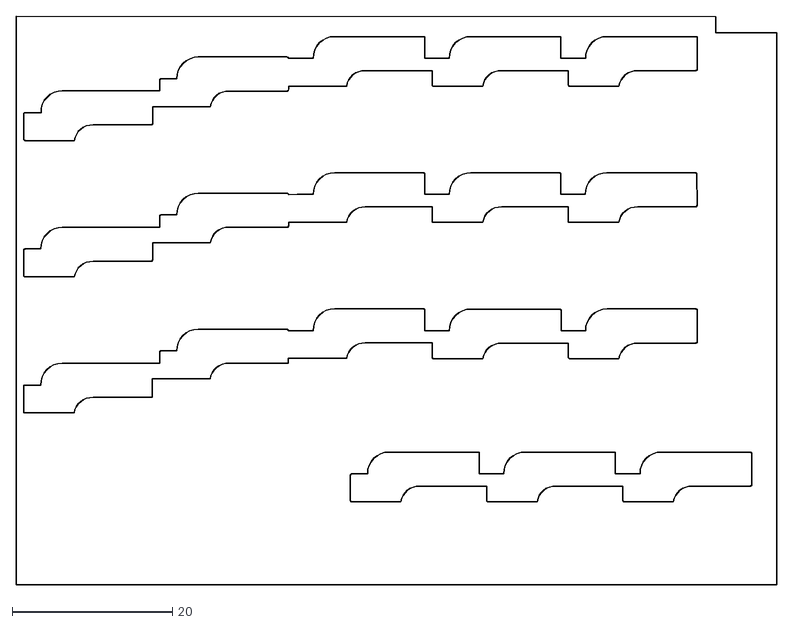
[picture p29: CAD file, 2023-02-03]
rev0.13/form/bottom__L__form.dxf
94.8 x 70.9

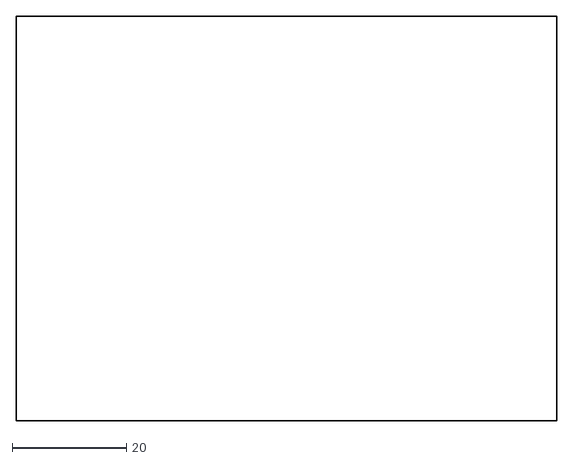
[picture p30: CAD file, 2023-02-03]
rev0.13/form/kicad_base_data/form_pcb_edge_support.dxf
94.8 x 70.8

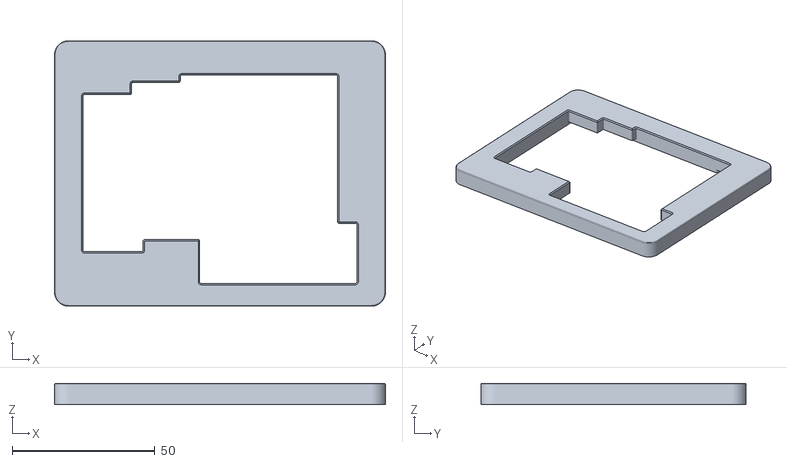
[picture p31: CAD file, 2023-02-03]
rev0.13/case/top__L.stl
115.8 x 92.8 x 7.50

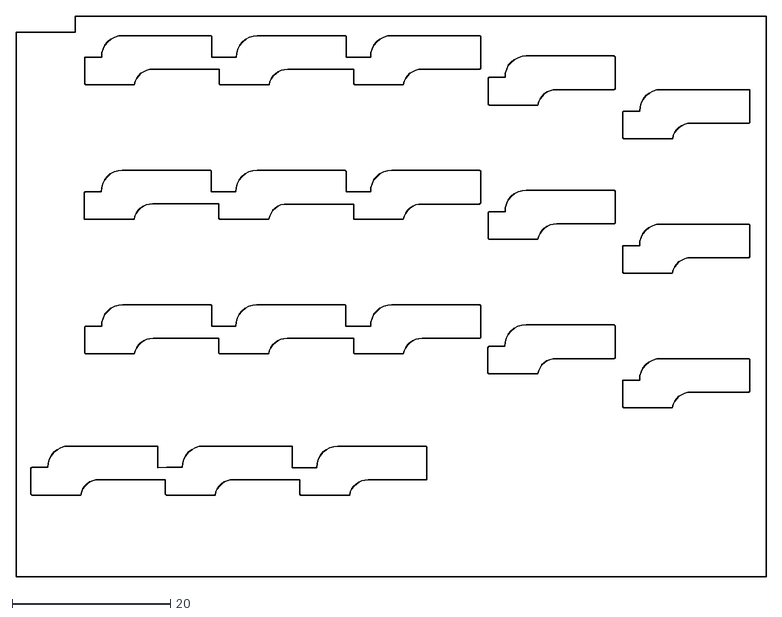
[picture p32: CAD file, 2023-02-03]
rev0.13/form/bottom__R__form.dxf
94.8 x 70.8

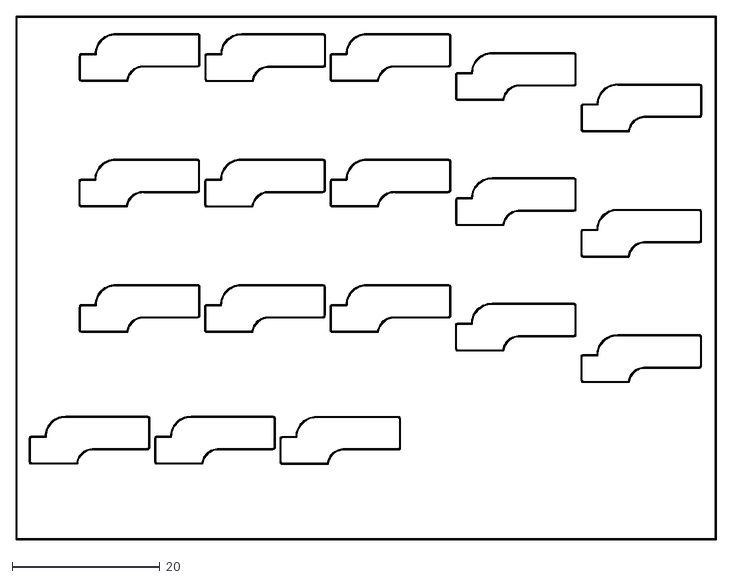
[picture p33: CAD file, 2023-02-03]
rev0.13/form/kicad_base_data/split-mini__form__right.dxf
94.9 x 71.0

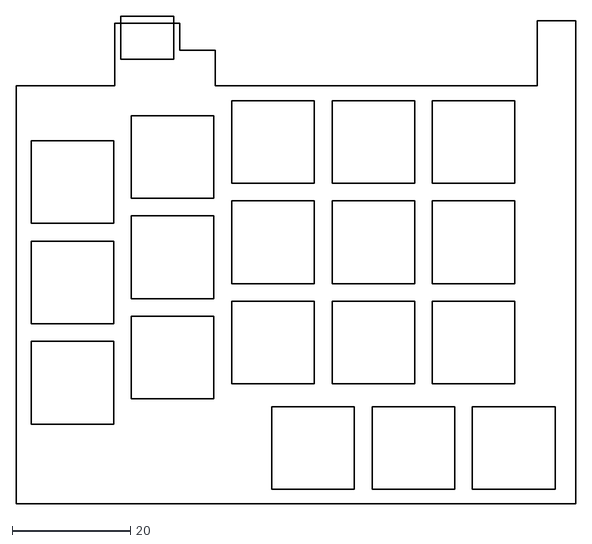
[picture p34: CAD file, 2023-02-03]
rev0.13/pcb support.dxf
94.8 x 82.7

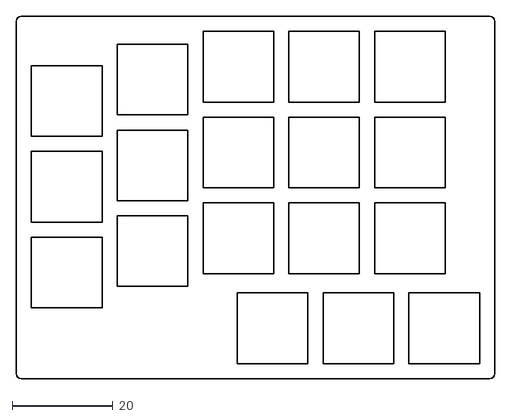
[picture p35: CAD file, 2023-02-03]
rev0.13/form/top__L__form.dxf
94.8 x 71.8

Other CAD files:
rev0.13/case/bottom__R.stl
rev0.13/case/bottom_thickness_18/bottom__L.stl
rev0.13/case/top__R.stl
rev0.13/swtich_plate__L.dxf
rev0.01/palmrest.FCStd
rev0.01/palmrest.stl
rev0.01/plate_base.dxf
rev0.01/split-mini-new.FCStd
rev0.02/plate_data.dxf
rev0.02/split-mini-new.FCStd
rev0.03/plate_data.dxf
rev0.03/split-mini-new.FCStd
rev0.12/base.dxf
rev0.12/bottom.dxf
rev0.12/edge.dxf
rev0.12/support.dxf
rev0.12/top.dxf
rev0.5/case/bottom_L.stl
rev0.5/case/bottom_R.stl
rev0.5/case/top_L.stl
rev0.5/case/top_R.stl
rev0.5/onshape_edge.dxf
rev0.5/onshape_support.dxf
rev0.5/plate_base.dxf
rev0.5/split rev0.5.dxf
rev0.6/edge_cut.dxf
rev0.6/palte_base.dxf
rev0.6/suppot_.dxf
rev0.6/top.dxf
rev0.7/edge_cut.dxf
rev0.7/plate_base.dxf
rev0.7/support.dxf
rev0.7/top.dxf
rev0.8/case/left.stl
rev0.8/case/left_with_palmrest.stl
rev0.8/case/right.stl
rev0.8/case/right_with_palmrest.stl
rev0.8/edge.dxf
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

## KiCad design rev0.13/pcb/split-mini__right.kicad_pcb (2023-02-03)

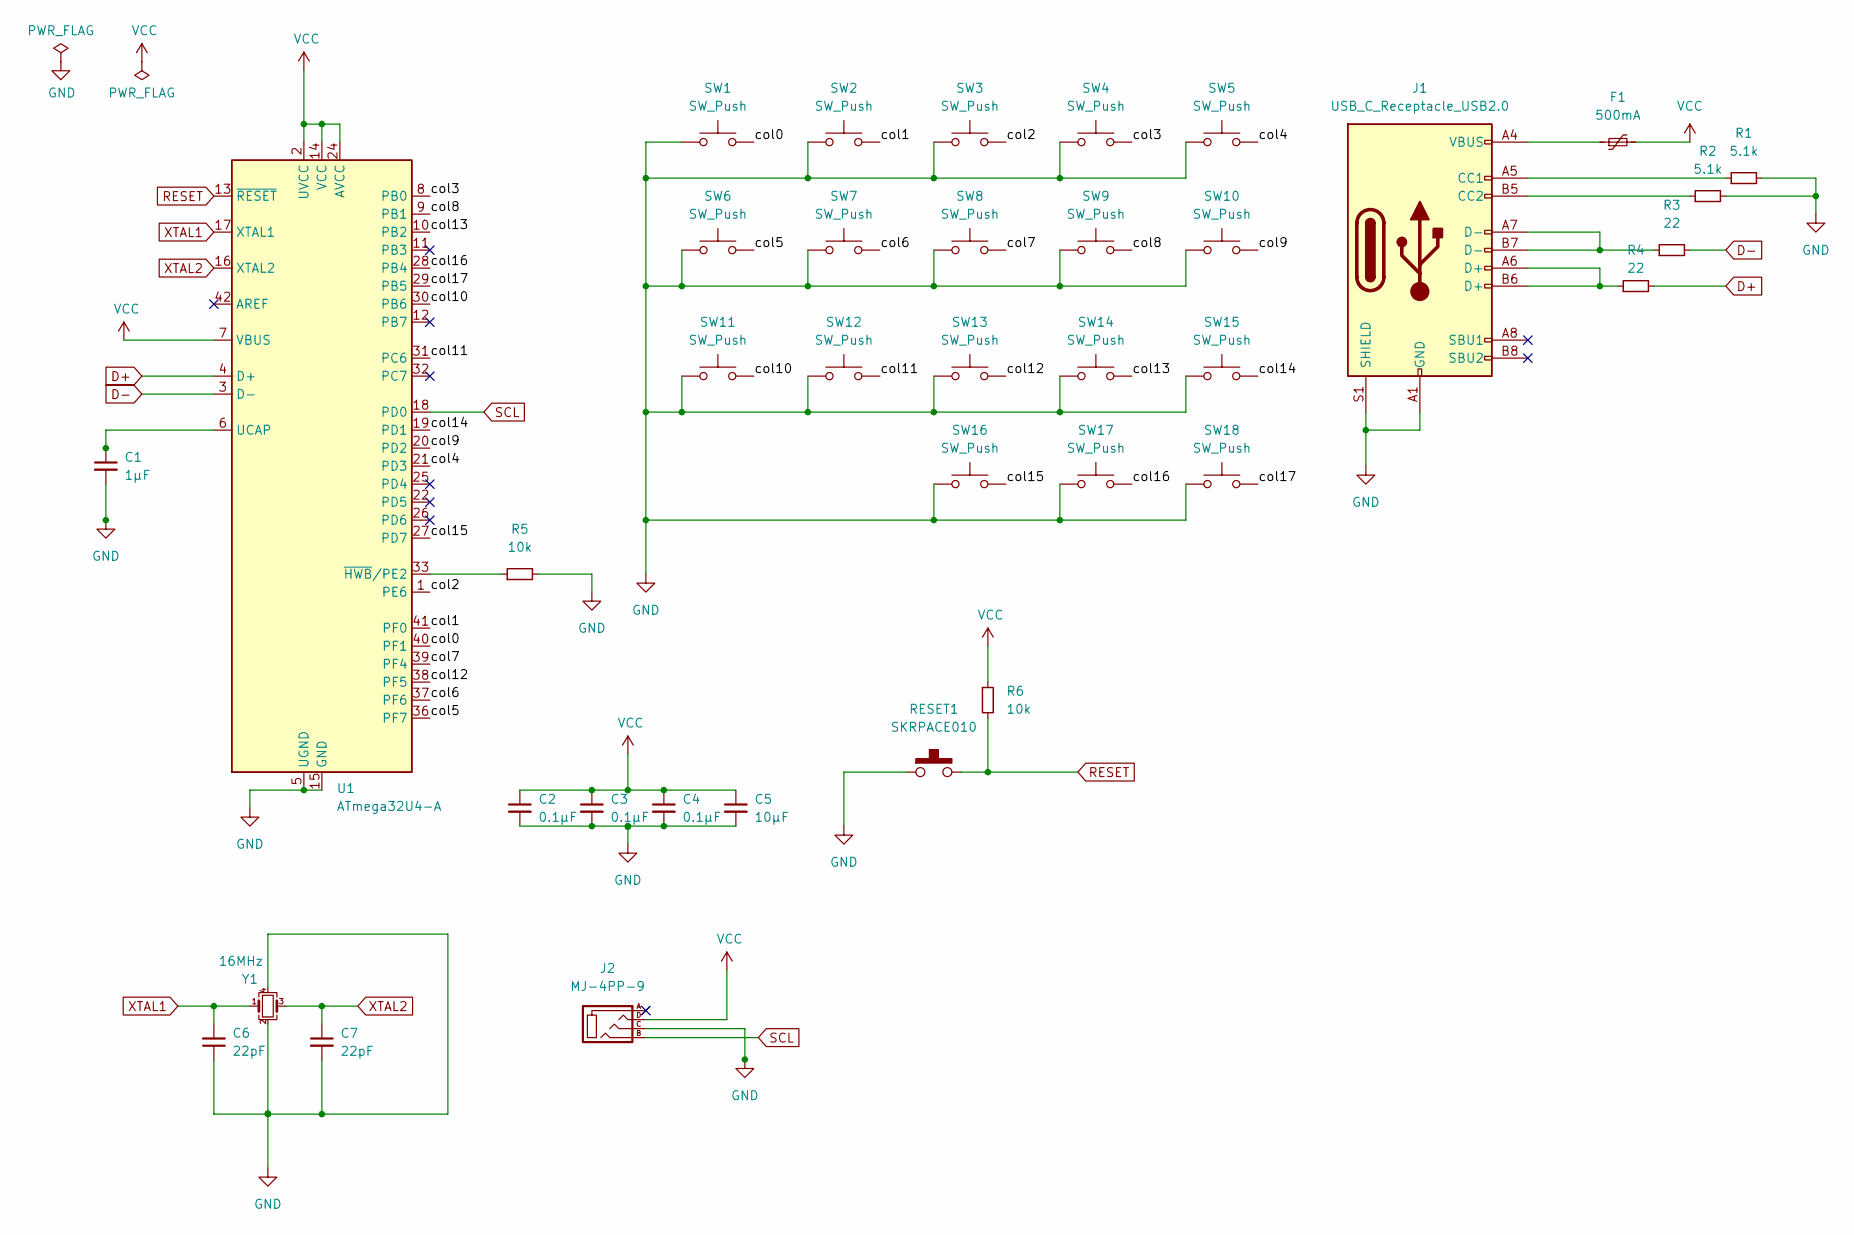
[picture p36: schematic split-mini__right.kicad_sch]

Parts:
C1: 1μF; C_0805_2012Metric; LCSC C28323
C2, C3, C4: 0.1μF; C_0805_2012Metric; LCSC C49678
C5: 10μF; C_0805_2012Metric; LCSC C440198
C6, C7: 22pF; C_0805_2012Metric; LCSC C1804
F1: 500mA; Fuse_1206_3216Metric; LCSC C883125
J1: USB_C_Receptacle_USB2.0; USB_C_Receptacle_Neltron_5077CR-16SMC2
J2: MJ-4PP-9; MJ-4PP-9_1side
R1, R2: 5.1k; R_0805_2012Metric; LCSC C17561
R3, R4: 22; R_0805_2012Metric; LCSC C17561
R5, R6: 10k; R_0805_2012Metric; LCSC C17414
RESET1: SKRPACE010; SKRPAxE010
SW1, SW2, SW3, SW4, SW5, SW6, SW7, SW8, SW9, SW10, SW11, SW12, SW13, SW14, SW15, SW16, SW17, SW18: SW_Push; CherryMX_Hotswap
U1: ATmega32U4-A; LQFP-44_10x10mm_P0.8mm
Y1: 16MHz; Crystal_SMD_SeikoEpson_FA238-4Pin_3.2x2.5mm_HandSoldering; LCSC C13738

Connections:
/col0: SW1.2, U1.40 (PF1)
/col1: SW2.2, U1.41 (PF0)
/col2: SW3.2, U1.1 (PE6)
/col3: SW4.2, U1.8 (PB0)
/col4: SW5.2, U1.21 (PD3)
/col5: SW6.2, U1.36 (PF7)
/col6: SW7.2, U1.37 (PF6)
/col7: SW8.2, U1.39 (PF4)
/col8: SW9.2, U1.9 (PB1)
/col9: SW10.2, U1.20 (PD2)
/col10: SW11.2, U1.30 (PB6)
/col11: SW12.2, U1.31 (PC6)
/col12: SW13.2, U1.38 (PF5)
/col13: SW14.2, U1.10 (PB2)
/col14: SW15.2, U1.19 (PD1)
/col15: SW16.2, U1.27 (PD7)
/col16: SW17.2, U1.28 (PB4)
/col17: SW18.2, U1.29 (PB5)
D+: R4.2, U1.4 (D+)
D-: R3.2, U1.3 (D-)
GND: C1.2, C2.2, C3.2, C4.2, C5.2, C6.1, C7.2, J1.A1 (GND), J1.A12 (GND), J1.B1 (GND), J1.B12 (GND), J1.S1 (SHIELD), J2.C, R1.2, R2.2, R5.2, RESET1.1 (A), RESET1.2 (B), SW1.1, SW2.1, SW3.1, SW4.1, SW5.1, SW6.1, SW7.1, SW8.1, SW9.1, SW10.1, SW11.1, SW12.1, SW13.1, SW14.1, SW15.1, SW16.1, SW17.1, SW18.1, U1.5 (UGND), U1.15 (GND), U1.23 (GND), U1.35 (GND), U1.43 (GND), Y1.2, Y1.4
unnamed: C1.1, U1.6 (UCAP)
unnamed: F1.1, J1.A4 (VBUS), J1.A9 (VBUS), J1.B4 (VBUS), J1.B9 (VBUS)
unnamed: J1.A5 (CC1), R1.1
unnamed: J1.A6 (D+), J1.B6 (D+), R4.1
unnamed: J1.A7 (D-), J1.B7 (D-), R3.1
unnamed: J1.B5 (CC2), R2.1
unnamed: R5.1, U1.33 (~HWB/PE2)
RESET: R6.2, RESET1.3 (C), RESET1.4 (D), U1.13 (~RESET)
SCL: J2.B, U1.18 (PD0)
VCC: C2.1, C3.1, C4.1, C5.1, F1.2, J2.D, R6.1, U1.2 (UVCC), U1.7 (VBUS), U1.14 (VCC), U1.24 (AVCC), U1.34 (VCC), U1.44 (AVCC)
XTAL1: C6.2, U1.17 (XTAL1), Y1.1
XTAL2: C7.1, U1.16 (XTAL2), Y1.3

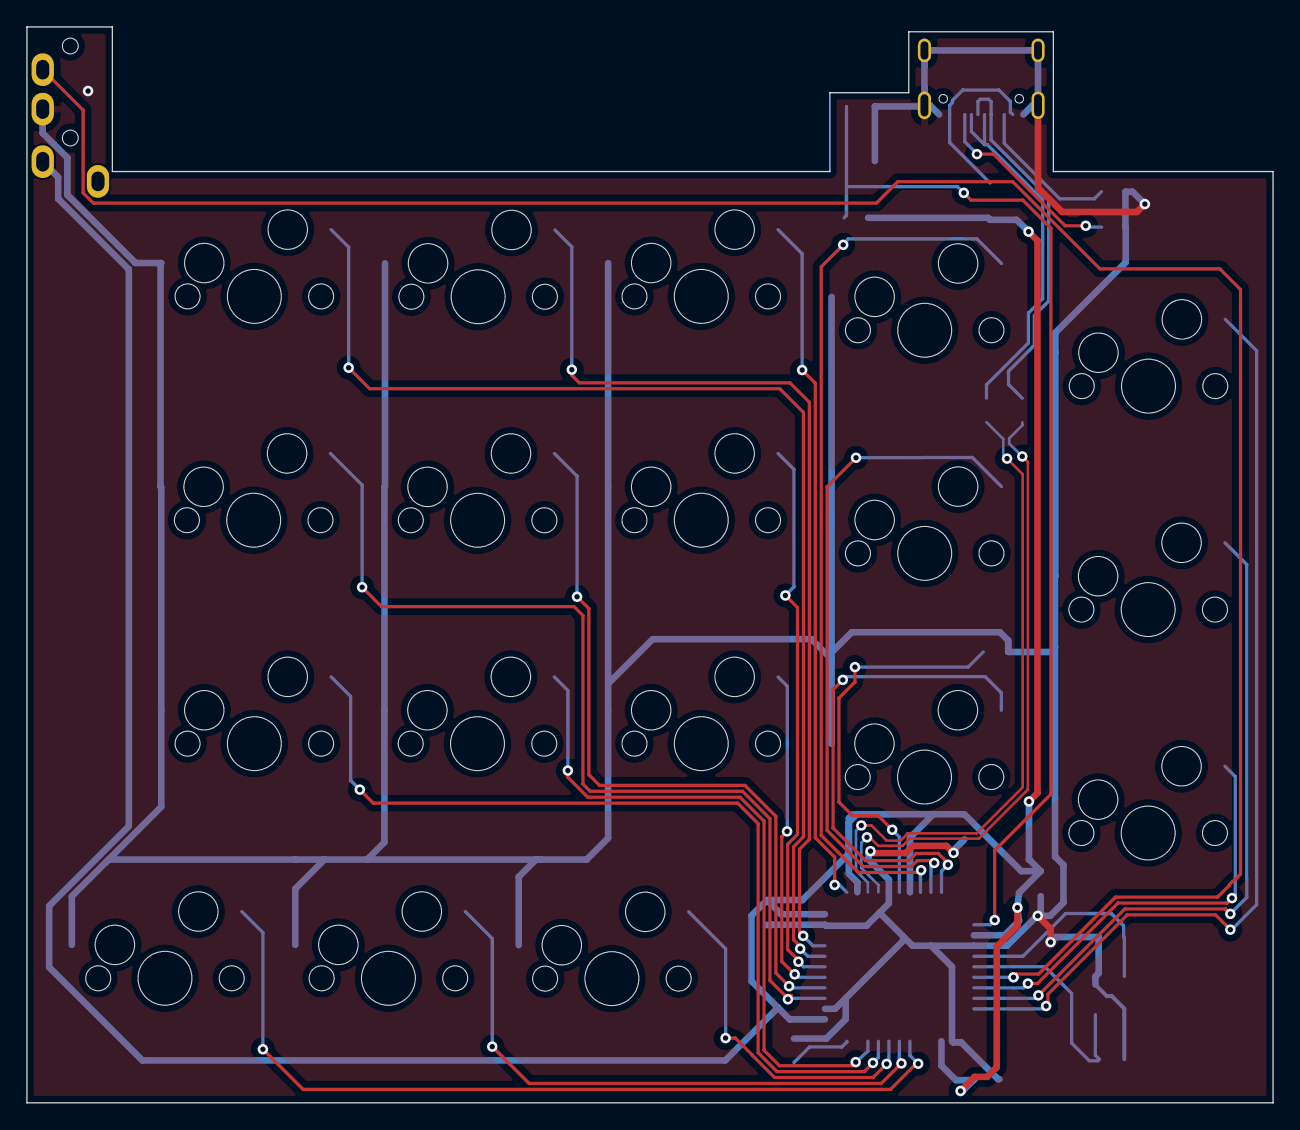
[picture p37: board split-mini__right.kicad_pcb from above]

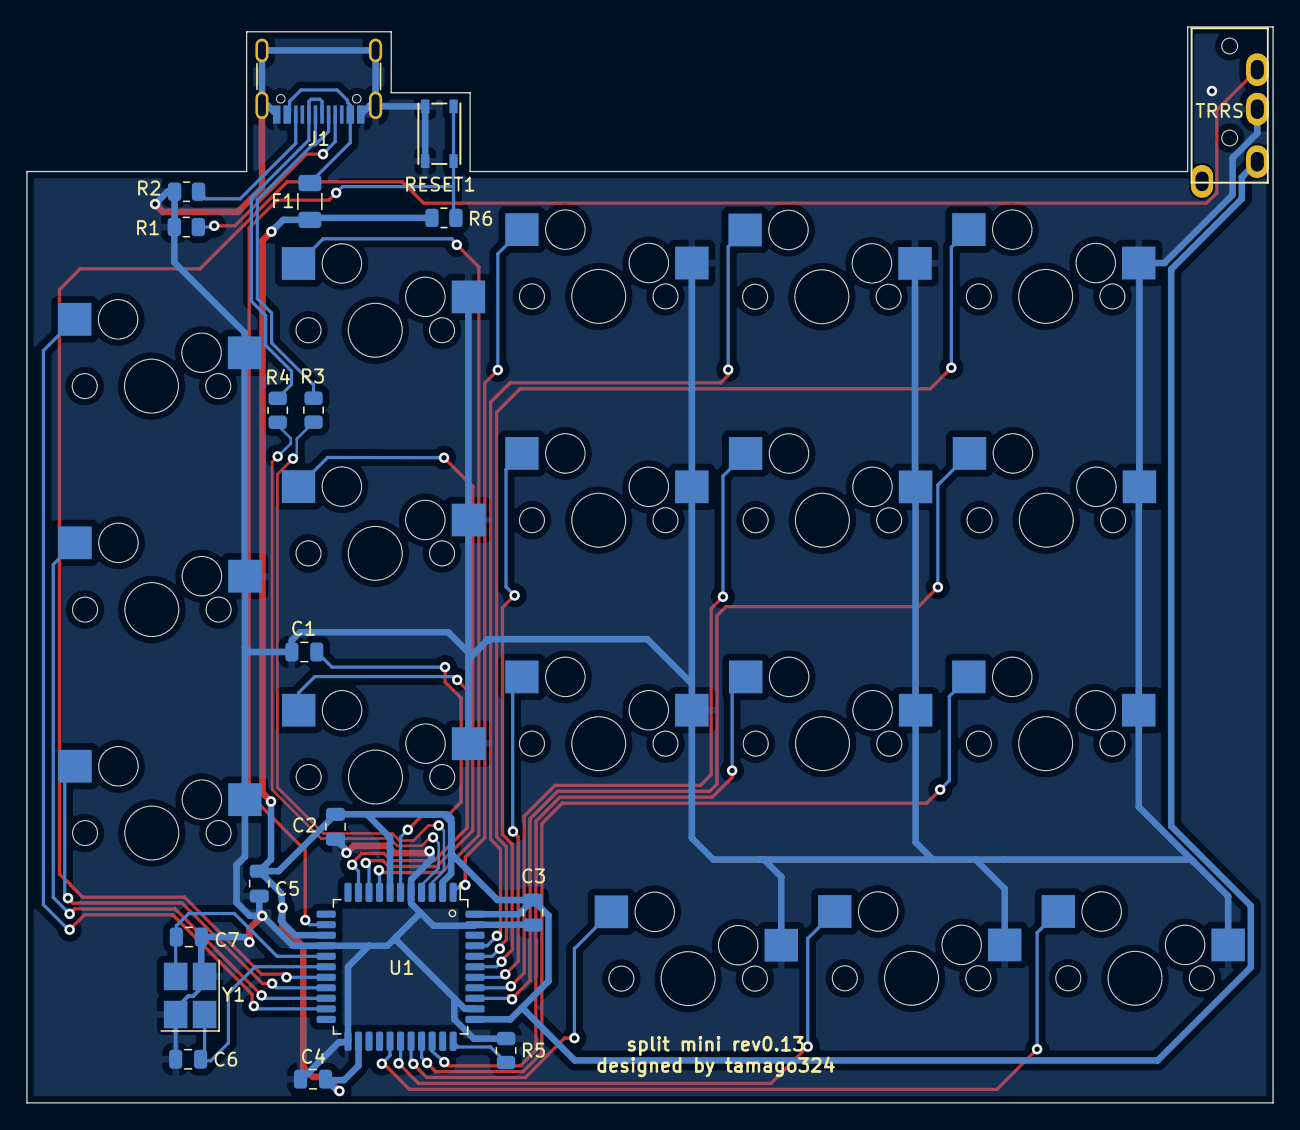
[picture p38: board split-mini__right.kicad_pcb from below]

Board: 2 copper layers, 94.8 x 81.8 mm, 37 parts (19 on the bottom side), 33 nets.

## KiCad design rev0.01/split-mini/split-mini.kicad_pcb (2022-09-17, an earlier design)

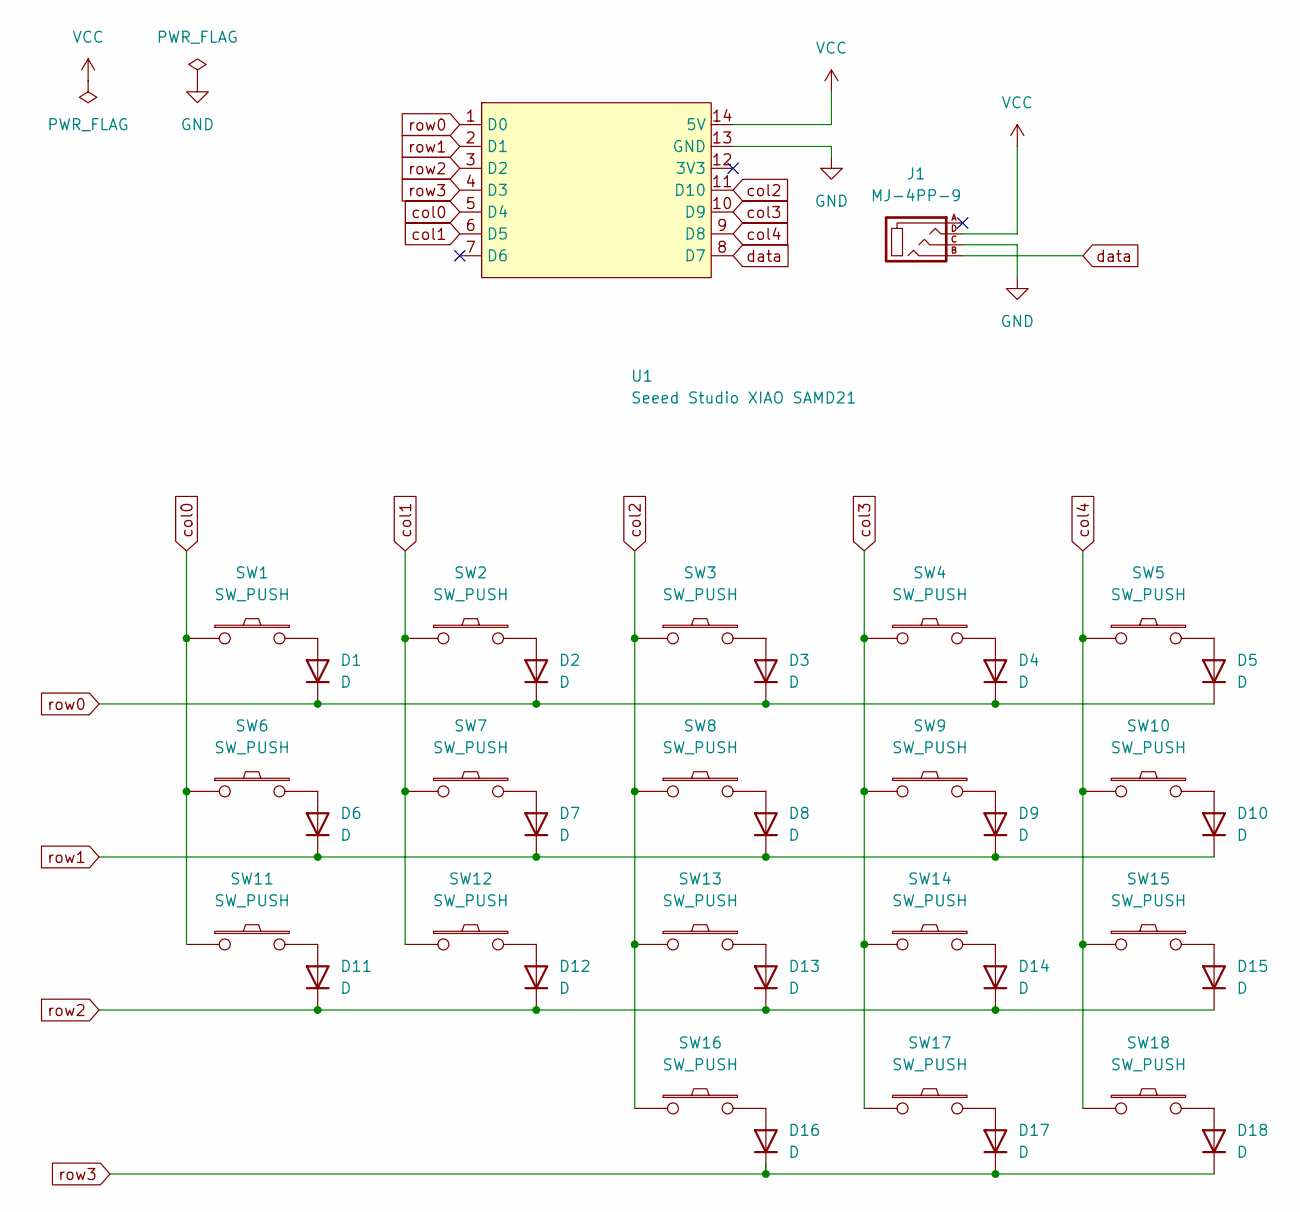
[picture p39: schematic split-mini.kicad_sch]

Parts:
D1, D2, D3, D4, D5, D6, D7, D8, D9, D10, D11, D12, D13, D14, D15, D16, D17, D18: D; D3_SMD
J1: MJ-4PP-9
SW1, SW2, SW3, SW4, SW5, SW6, SW7, SW8, SW9, SW10, SW11, SW12, SW13, SW14, SW15, SW16, SW17, SW18: SW_PUSH; CherryMX_MidHeight_Hotswap_mod
U1: Seeed Studio XIAO SAMD21; XIAO-RP2040_mod

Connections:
GND: J1.C, U1.13 (GND)
unnamed: D1.2 (A), SW1.2
unnamed: D2.2 (A), SW2.2
unnamed: D3.2 (A), SW3.2
unnamed: D4.2 (A), SW4.2
unnamed: D5.2 (A), SW5.2
unnamed: D6.2 (A), SW6.2
unnamed: D7.2 (A), SW7.2
unnamed: D8.2 (A), SW8.2
unnamed: D9.2 (A), SW9.2
unnamed: D10.2 (A), SW10.2
unnamed: D11.2 (A), SW11.2
unnamed: D12.2 (A), SW12.2
unnamed: D13.2 (A), SW13.2
unnamed: D14.2 (A), SW14.2
unnamed: D15.2 (A), SW15.2
unnamed: D16.2 (A), SW16.2
unnamed: D17.2 (A), SW17.2
unnamed: D18.2 (A), SW18.2
VCC: J1.D, U1.14 (5V)
col0: SW1.1, SW6.1, SW11.1, U1.5 (D4)
col1: SW2.1, SW7.1, SW12.1, U1.6 (D5)
col2: SW3.1, SW8.1, SW13.1, SW16.1, U1.11 (D10)
col3: SW4.1, SW9.1, SW14.1, SW17.1, U1.10 (D9)
col4: SW5.1, SW10.1, SW15.1, SW18.1, U1.9 (D8)
data: J1.B, U1.8 (D7)
row0: D1.1 (K), D2.1 (K), D3.1 (K), D4.1 (K), D5.1 (K), U1.1 (D0)
row1: D6.1 (K), D7.1 (K), D8.1 (K), D9.1 (K), D10.1 (K), U1.2 (D1)
row2: D11.1 (K), D12.1 (K), D13.1 (K), D14.1 (K), D15.1 (K), U1.3 (D2)
row3: D16.1 (K), D17.1 (K), D18.1 (K), U1.4 (D3)

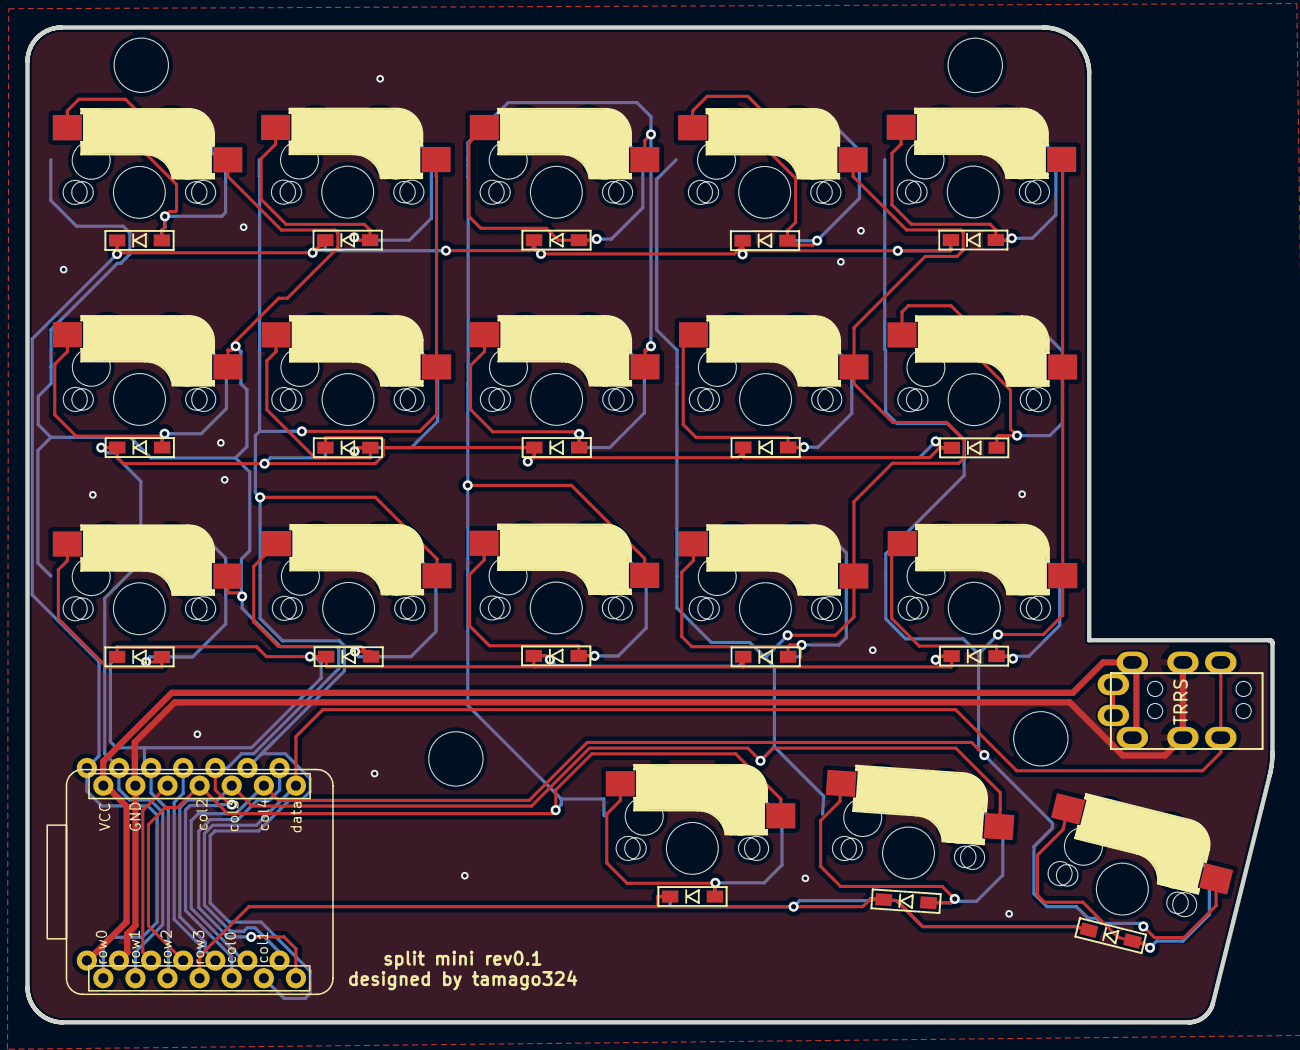
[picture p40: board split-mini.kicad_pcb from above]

Board: 2 copper layers, 98.5 x 78.7 mm, 42 parts (0 on the bottom side), 30 nets.

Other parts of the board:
Ref1: Val1; M2_HOLE_v2_4.3mm
Ref2: Val2; M2_HOLE_v2_4.3mm
Ref3: Val3; M2_HOLE_v2_4.3mm
Ref4: Val4; M2_HOLE_v2_4.3mm

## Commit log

2022-09-19 rev0.1 のREADME.md を修正
2022-09-19 rev0.1 の READMD を修正
2022-09-19 rev0.2 の README を修正
2022-10-07 add rev0.3
    [plate_data.dxf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]
2022-10-07 画像追加
2022-11-03 rev0.4 を追加
    [bottom_plate__split-mini-B_Cu.gbr, bottom_plate__split-mini-B_Mask.gbr, bottom_plate__split-mini-B_Silks.gbr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]
2022-11-03 kle の URL を追加
2022-11-22 rev0.5 を追加
    [bottom_L.stl, bottom_R.stl, onshape_edge.dxf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]
2022-11-22 rev0.4 を削除
    [bottom_plate__split-mini-B_Cu.gbr, bottom_plate__split-mini-B_Mask.gbr, bottom_plate__split-mini-B_Silks.gbr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]
2022-11-23 rev0.5 の REWADME を更新
2022-11-30 いろいろ追加
    [edge.dxf, edge_cut.dxf, left.stl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]
2022-11-30 update 写真を追加
    [palmrest_L.stl, palmrest_R.stl]
2022-11-30 fix case link
2022-12-13 add rev0.9
    [bottom_L.stl, bottom_R.stl, edge_cut.dxf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]
2023-01-03 rev.0.12 を追加
    [base.dxf, bottom.dxf, edge.dxf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]
2023-02-03 add rev0.13
    [base.dxf, bottom__L.stl, bottom__L__form.dxf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]
2023-02-06 prk_firmware 削除

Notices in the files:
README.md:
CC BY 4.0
